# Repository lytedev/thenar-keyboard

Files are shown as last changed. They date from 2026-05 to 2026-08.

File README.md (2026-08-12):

# Thenar

A column-staggered, fully-wireless split keyboard with scrollwheels — 56 keys (28 per half + thumb cluster). Choc-spaced, hotswap, Nice!Nano + ZMK.

## Repositories

- **Primary**: <https://git.lyte.dev/lytedev/thenar-keyboard>
- **Mirror (GitHub)**: <https://github.com/lytedev/thenar-keyboard>
- **Sibling model**: [hypothenar](https://git.lyte.dev/lytedev/hypothenar-keyboard) — the pick-and-place (JLCPCB PCBA) sibling: same layout, completely different electronics ([GitHub mirror](https://github.com/lytedev/hypothenar-keyboard))

- Choc-spaced, hot-swappable
- Scrollwheel (`EVQWGD001`) on both sides
- Strong pinky stagger (0.66) and a 5 deg. pinky splay
- Fully wireless built for Nice!Nano + ZMK (no TRRS jack)
- Nice!View support (5 pin connector)
- Reversible PCB
- 3d printable magnetic case, switchplate and MCU cover

## Gallery

TODO: Take photos of the assembled Thenar and add them here.

## Firmware

Natively supports [ZMK](https://zmk.dev/). Build + flash via the flake:

```sh
nix build .#firmware             # both halves
nix run .#flash -- left          # build + flash (double-tap reset when prompted)
nix run .#flash -- right
```

The shield definition + keymap live in [`config/`](./config/).
See `config/README.md` for the full firmware development workflow,
including hash-pinning the Zephyr SDK on first build.

## Build guide

[see the docs](./docs/) — [build](./docs/build.md), [routing](./docs/routing.md). Both are LLM-drafted and unverified; treat them as starting points until someone has built and routed a Thenar end-to-end.

## Development

The build has two phases:

1. **Ergogen produces a scaffold** — KiCad PCBs with all the footprints
   placed and nets assigned, but **no copper routing**. This is the
   starting point.
2. **A human routes the scaffold in KiCad by hand** and commits the
   result to `thenar/routed/`. Gerbers are then exported from the
   committed routed file, not from the ergogen scaffold.

This is unavoidable: ergogen is a layout generator, not an autorouter, and
a useful keyboard PCB needs every net wired up by hand to fit two layers.

### Flake packages

```sh
nix build .#scaffold          # ergogen -> KiCad PCBs (UNROUTED, for hand-routing)
nix build .#gerbers           # gerbers from thenar/routed/keyboard.kicad_pcb
nix build .#gerbers-zip       # ^^ zipped, ready to upload to JLCPCB etc. (default)
nix build .#switchplate-step  # STEP model of the switchplate (1.2mm)
nix flake check               # verifies thenar/routed/ placement matches scaffold
```

Each `result` symlink points at the artifact in `/nix/store`. For an
interactive shell with `ergogen`, `kicad-cli`, and `zip` available:

```sh
nix develop
```

### The two paths to fab-ready gerbers

- **Use the committed routed PCB.** `nix build .#gerbers-zip` and upload
  the result. This is the default path and the only one that has a chance
  of working without you doing any routing yourself.
- **Route your own.** Run `nix build .#scaffold`, open
  `result/pcbs/keyboard.kicad_pcb` in KiCad, route every net, save the
  routed file over `thenar/routed/keyboard.kicad_pcb`, then
  `nix build .#gerbers-zip`. If you fork the repo, commit your routed
  PCB so anyone using your fork gets it for free.

`nix flake check` runs `check-routing-drift`, which compares footprint
placement between the freshly-generated scaffold and the committed
`thenar/routed/` PCB. If you edit `thenar/ergogen/config.yaml` without
re-merging into the routed file, this check will fail loudly.

## License

MIT — see [LICENSE](LICENSE).

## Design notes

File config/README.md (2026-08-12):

# Thenar ZMK config / shield

The Thenar ZMK shield module + a build setup so `nix build .#firmware`
and `nix run .#flash -- (left|right)` work locally without GitHub
Actions.

## Building + flashing

```sh
# Build both halves -> a derivation containing zmk_left.uf2 + zmk_right.uf2.
nix build .#firmware

# Or just one half (each produces a .uf2 directly):
nix build .#firmware-left
nix build .#firmware-right

# Flash one half. Double-tap reset on the Nice!Nano when prompted.
nix run .#flash -- left
nix run .#flash -- right
```

The first build will fail with a `zephyrDepsHash` mismatch — paste the
hash nix reports into `flake.nix` (`zephyrDepsHash = ...`) and rebuild.
This hash pins the Zephyr SDK + west modules so subsequent builds are
hermetic.

## Files

- `west.yml` — west manifest. Pulls upstream ZMK and points west at this
  directory's `boards/` for shield discovery.
- `build.yaml` — ZMK CI matrix (for GitHub Actions / similar). Not used
  by the local nix build, but useful if you want to add CI later.
- `thenar.keymap` — the keymap zmk-nix's `buildSplitKeyboard` picks up.
  The only keymap in the repo; edit here.
- `boards/shields/thenar/`
  - `Kconfig.shield` / `Kconfig.defconfig` — Kconfig entries for the shield.
  - `thenar.dtsi` — matrix transform, encoder, sensor declarations.
  - `thenar-layouts.dtsi` — physical key positions (for ZMK Studio).
  - `thenar_left.overlay` / `thenar_right.overlay` — per-half GPIO + SPI.

## Hardware specifics

- **Matrix**: 5×12 (5 scan rows × 12 columns; 6 per half with `col-offset=6` on right).
- **Diode direction**: `col2row`.
- **Encoder (EVQWGD001 scrollwheel)**: `alps,ec11` compatible. Left half
  uses Nice!Nano P20/P21, right uses P2/P3.
- **Display (Nice!View)**: SPI0; left CS=P4, right CS=P19.

## Forking for a personal keymap

Easiest path: clone this repo, edit `config/thenar.keymap`, build with
`nix build .#firmware-left` / `nix build .#firmware-right`. Your keymap
edits stay in your fork.

For the "proper" ZMK ecosystem flow (separate config repo that pulls in
the shield as a remote module), point your `config/west.yml` at this
repo's `config/boards/` directory and define `shield: thenar_left` /
`thenar_right` in your build matrix.

## TODO before the firmware is fully verified

- **Matrix transform verification**: the mod-row matrix coords (`RC(4,1..4)`
  and `RC(4,7..10)`) were derived from `thenar/ergogen/config.yaml`'s
  `column_net`/`row_net` overrides. Could be off by one in the mod row.
  Press every key after flashing and check ZMK's matrix scan output.
- **Physical layout refinement**: `thenar-layouts.dtsi` coords are
  placeholder approximations of the corax layout adjusted for our
  extra outer-num key. Real values come from a built keyboard.
- **`thenar.zmk.yml`**: ZMK Studio metadata, add once the layout's stable.

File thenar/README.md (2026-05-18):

# Thenar

A 56-key column-staggered split keyboard with scrollwheels. 28 keys per half (5×6 matrix minus skipped corners + 2 thumb keys + scrollwheel).

## Bill of materials

**Essentials**:
| **Item** | **Count** | **Note** |
|---|---|---|
| Keyboard PCB | 2 | |
| Nice!Nano | 2 | |
| 12 pin headers and sockets | 4 | You can use through-hole diode legs as pins. Sockets spacing: 2.54mm, Socket height: Using minimal height sockets might not leave enough room to mount the battery under the MCU. 3DS1002-01-1*20V13-JK by CONNFLY are a good choice, but you can also use lower ones and longer legs instead. Spiltkb has a good [guide on mounting](https://docs.splitkb.com/hc/en-us/articles/360011263059).  |
| LiPo battery (301230) | 2 | 110mAh |
| Kailh Choc v1 switches (PG1350) | 56 | |
| Keycaps | 56 | |
| Kailh Choc hotswap sockets | 56 | |
| Encoder EVQWGD001 | 2 | |
| Diodes 1N4148W | 58 | for each key + encoder |
| Buttons | 2 | reset buttons; 2 pins through-hole, tactile, 3x6x4.3mm |
| Slider Switches | 2 | on/off switches; SMD, C128955 |
| USB-C Cable | 1 | for copying the firmware 

**Optional (Displays, 3d printed case)**:

| **Item** | **Count** | **Note** |
|---|---|---|
| Nice!View + mounts | 2 | |
| Switchplate | 2 | Height: 1.2mm; either 3d printed or cut pcbs. [stl](./3dprints/switchplate/) |
| Case (Left + Right) | 1 | see [here](./3dprints/case/). |
| Silicone feet | 8 | |

## Firmware

A ZMK shield module ships in this repo at [`firmware/`](../firmware/).
See `firmware/README.md` for how to wire it into your personal
ZMK config. The module defines the matrix, encoder, and display
hardware; the default keymap is minimal QWERTY for first-flash
verification — you'll want to fork it into a separate config repo
and customise.

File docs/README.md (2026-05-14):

# Thenar docs

- [build.md](./build.md) — assembly walkthrough (order PCBs, solder, flash).
- [routing.md](./routing.md) — how to take the ergogen scaffold to a
  routed PCB ready for fab. Only needed if you are routing yourself; the
  committed `thenar/routed/` PCB is the default path.

Both guides are currently LLM-drafted and unverified. Corrections welcome
once anyone has actually built or routed a Thenar.

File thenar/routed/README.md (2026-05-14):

# Routed PCB

This directory holds the **manually-routed** KiCad PCBs that gerbers are built
from. Ergogen places footprints and assigns nets, but does not route copper —
that step has to be done by hand in KiCad. The result of that hand-routing
lives here and is committed.

## Workflow

1. `nix build .#pcbs` produces the ergogen scaffold (footprints + nets, no
   traces) at `result/pcbs/keyboard.kicad_pcb`.
2. The first time, that scaffold is copied verbatim into this directory as a
   seed. You then open it in KiCad and route the traces by hand. Commit the
   routed file.
3. `nix build .#gerbers` reads the routed file *from here* — not from the
   ergogen output — and produces fabricatable gerbers.
4. If you edit `thenar/ergogen/config.yaml` (e.g. moving a key, adding a
   footprint), the ergogen scaffold and this routed file go out of sync.
   Run `nix flake check` (or `nix build .#check-routing-drift`) to catch
   that — it compares footprint placement between the freshly-generated
   scaffold and this committed PCB. When drift is detected, you need to
   merge the new footprint placement back into the routed PCB in KiCad
   (KiCad can do this incrementally via "Update PCB from Schematic" style
   workflows, but with ergogen the simplest path is usually: open the new
   scaffold, copy your routing over from the old routed file, and re-save).

## Current state

> **⚠️ Currently unrouted.** The files here are a verbatim copy of the
> ergogen output. They will produce empty/unusable gerbers until someone
> opens them in KiCad and routes the traces. Do **not** order PCBs from
> the current gerber output.

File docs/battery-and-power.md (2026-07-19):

# Battery & power

How the thenar is powered, and the clean split between **rev1 (rc1)** —
the boards already fabricated, which need a battery-wiring rework — and
**rev2** — the updated design that fixes it properly.

> **Revisions.** `git tag hw-rev1` freezes the as-fabricated rev1 PCB.
> `main` evolves into rev2 in place; recover rev1 files with
> `git show hw-rev1:thenar/routed/keyboard.kicad_pcb`.

## Background: how the nice!nano v2 power path works

One fact drives everything below: on the nice!nano v2 the **battery, the
onboard charger's output, and the MCU's supply are all the same node —
`B+` / VDDH**.

- **B+ / B-** (underside pads): the battery connects here. B+ feeds both
  the onboard charge IC (charges from USB 5 V) *and* the nRF52840's
  **VDDH**, which is the pin ZMK measures for battery level.
- **RAW**: a *separate* 5 V input that feeds only the 3.3 V regulator.
  RAW is **not** charged and **not** sensed.

So a cell on RAW powers the board but is invisible to both the charger
and the gauge. And because B+ = charger = MCU supply are one node, you
**cannot** hard-switch the MCU off while still charging the cell — those
are the same wire. "Off but charging" is only achievable *electronically*
(ZMK soft-off, ~µA), not with a mechanical cut. Both facts shape the
rev1 rework and the rev2 design.

---

## rev1 (rc1): the as-fabricated boards

### The problem

`thenar/ergogen/config.yaml` (at `hw-rev1`) wires **battery+ → slider →
the nice!nano RAW pin**; the B+/B- pads are unconnected. Consequences on
a board in hand:

- **Battery level reads a flat ~0%** — VDDH/B+ sits at ~0 V, so ZMK
  computes 0% regardless of real charge. (Multimeter check: B+ to GND ≈
  0 V, RAW to GND ≈ cell voltage.)
- **USB does not charge the LiPo** — the charger charges B+, which has no
  cell. USB powers the board but the battery only drains. Charge the cell
  externally until reworked.

Not a firmware bug — ZMK reads the board's built-in VDDH sensor and can't
be pointed at RAW. It's a wiring problem, forced by the footprint:
`mcu_nice_nano.js` exposes only the castellated edge pins (RAW/GND/VCC/
RST/Pxx) and **no B+/B- pads**, so RAW was the only power-input pad
available.

### The rework (existing boards)

The nice!nano is socketed on headers with the LiPo sitting in the gap
underneath it, so the module's underside B+/B- pads face the battery —
a short direct wire.

**Basic (working battery, ~5 min):**

1. Solder LiPo **+ → module B+**, **- → module B-** (B- is just GND).
2. Take the cell **off** the JST/slider/RAW path (don't leave it on both
   B+ and RAW — that's a conflict).
3. Result: correct battery %, USB charging works. The **slider is now
   dead** (it sat in the RAW path); "off" is ZMK's automatic deep-sleep.

**Advanced (also get the slider back as a soft-off switch):** additionally
rewire the slider off the power rail and onto spare GPIO **P0** (other
terminal to GND), and enable soft-off in firmware (see rev2 firmware
notes — the same config works on a reworked rev1 board). Then the slider
becomes a real on/off that still charges while off.

---

## rev2: updated power design

Goal the user asked for: **the slider turns the keyboard off, and it can
still charge while off.** Given the nice!nano constraint above, that means
**soft-off**, not a hard cut.

### Design

- **Battery → B+/B-.** The board gains labeled B+/B- solder pads (with
  silk "→ nice!nano B+/B-") in the battery cavity; the builder runs the
  short wire up to the module. Nothing routes to RAW. This restores
  sensing + USB charging by construction.
- **Slider → spare GPIO `P0`** (not the power rail). Wired as a ZMK
  **soft-off trigger + wake source**: slide off → System OFF (~5–15 µA);
  slide on → wake.
- **Charging is autonomous** — the onboard charger runs regardless of MCU
  state, so USB charges the cell whether awake or in soft-off. ✅

### What users get (matches commercial/premium wireless UX)

Plug in USB → it charges. OS shows a real battery %. Flip the slider →
stops typing, sleeps at µA. Flip back → wakes instantly, BT bond intact.
Charges in any switch position — like a Logitech/Apple keyboard, unlike
the common DIY hard-cut switch.

### The one tradeoff

Soft-off is ~µA, not a *true* zero-current disconnect — B+ stays lightly
energized. So it's slightly weaker than a hard battery cut for the
**spill** scenario. On a nice!nano you can't have both hard-disconnect
*and* charge-while-off; rev2 chooses charge-while-off. See
[spill-protection](spill-protection.md) — its "cut battery power" step is
now a soft-off, not a hard cut.

### Firmware (soft-off)

rev2 (and advanced-reworked rev1) needs ZMK soft-off enabled and the P0
slider configured as a soft-off trigger + wake source. Battery reporting
stays enabled — it's correct the moment a board has the cell on B+/B-.

Kept **out of the active firmware** deliberately: it can't be validated
until a board actually has the slider on P0, and the exact soft-off DT is
ZMK-version-specific. Apply this once you've reworked/built a rev2 board,
then bench-test. Reference: <https://zmk.dev/docs/features/soft-off>.

`config/thenar.conf`:

```
CONFIG_ZMK_PM_SOFT_OFF=y
```

Shield overlay — scaffold (validate against ZMK v0.3.0's soft-off API and
**confirm the P0 → &pro_micro/&gpio index** against the nice!nano pinout
before flashing):

```dts
/ {
    soft_off_key: soft_off_key {
        compatible = "gpio-keys";
        key {
            // P0 slider -> GND (ACTIVE_LOW). Map <PIN> to the nice!nano
            // P0 pad's actual GPIO - do NOT assume; check the pinout.
            gpios = <&pro_micro PIN (GPIO_ACTIVE_LOW | GPIO_PULL_UP)>;
        };
    };
    soft_off_scan: soft_off_scan {
        compatible = "zmk,kscan-gpio-direct";
        input-keys = <&soft_off_key>;
        wakeup-source;
    };
    soft_off_wakers {
        compatible = "zmk,soft-off-wakeup-sources";
        wakeup-sources = <&soft_off_scan>;
    };
};
```

Then bind `&soft_off` to the soft-off scan's key (per the ZMK doc's
dedicated-kscan pattern). Slide off → `&soft_off` fires → System OFF;
slide on → the wakeup source re-enables the board.

**Spare GPIO confirmed:** `P0` (and `P1`) break out to self-named nets on
the nice!nano footprint, used nowhere else in the matrix/encoder/display,
so P0 is free for this.

### Implementation status

- [x] Documented (this file) + rev1 frozen at `hw-rev1`
- [x] `thenar/ergogen/config.yaml`: battery+ off RAW → isolated
      `BAT_BPLUS` wire-out pad; slider → `SOFT_OFF` (nice!nano P0) / GND;
      silk labels. Validated: `ergogen` regenerates cleanly, `switch_from`
      gone, `BAT_BPLUS`/`SOFT_OFF` nets present.
- [x] Firmware soft-off scaffold documented (above), kept out of active
      firmware until there's hardware to validate it on
- [ ] **Re-route `thenar/routed/keyboard.kicad_pcb`** — it is now
      rev1-stale vs the rev2 ergogen source. Regenerate with
      `nix build .#routed-auto` (~25 min, ~95%), finish the last traces +
      DRC in KiCad, then `cp` into `thenar/routed/`. The `routing-check`
      flake check will fail until this is done (placement drifted).
- [ ] Bench-test soft-off + charge-while-off on a reworked board

### Reroute recipe (two paths)

The rev2 electrical delta is tiny (a couple of traces in one corner), so
you don't need a full reroute — pick whichever is less work:

**Path A — delta-patch your hand-routed board (recommended).** Open the
current `thenar/routed/keyboard.kicad_pcb` (your good rev1 hand-route) in
KiCad and change only these four pad nets:

| Pad | net now | net for rev2 |
|-----|---|---|
| battery **+** | `switch_from` | `BAT_BPLUS` (isolated — no trace; it's the B+ wire-out) |
| slider pad 1  | `switch_from` | `SOFT_OFF` |
| slider pad 2  | `RAW` | `GND` |
| nice!nano **P0** | `P0` | `SOFT_OFF` |

Then: delete the `switch_from` traces (battery+↔slider) and the
slider→RAW trace; route one short trace slider pad1 → P0 (`SOFT_OFF`);
let slider pad2 tie to `GND` (via the ground zone, maybe a stub); add the
two silk labels; DRC. ~99% of the hand-routing is untouched.

*(Scriptable via `pcbnew` but not done here — the edit can't be visually
verified from a headless session and the delta is small enough that
doing it in-GUI, where you see + DRC it, is safer.)*

**Path B — full autoroute (fallback).** `nix build .#routed-auto`
(~25 min, ~95%) machine-routes the whole board from the rev2 scaffold;
finish the last ~5% + DRC in KiCad. Downside: throws away the rev1
hand-routing, so you re-verify everything. A fresh build already sits at
`/tmp/thenar-routed-rev2/keyboard.kicad_pcb` (gc-rooted) if useful as a
reference — note `BAT_BPLUS` is intentionally a single-pad net (no trace).

Either path lands in `thenar/routed/keyboard.kicad_pcb`; commit the
finished board and the `routing-check` goes green again.

---

## The hypothenar does NOT have the rev1 problem

The hypothenar is a from-scratch power design (MS88SF3 + its own TP4056 +
LDO + sense divider) that routes **everything to one `VBAT` net** — cell,
charger BAT pin, MCU VDDH, and a GPIO-switched ADC divider all share it —
so it senses and charges the real cell. See
`hypothenar-keyboard/docs/power-budget.md`. Because it has its *own*
charge IC (not the nice!nano's fused B+ node), a true **hard-off that
still charges** is designable there (battery always on the TP4056, a load
switch to the MCU) — a v-next consideration, not a v1 thing. Bring-up
check: confirm the divider's high side is on `VBAT` (post-slider).

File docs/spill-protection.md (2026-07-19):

# Spill protection

Making the thenar survive a desk spill. This is **splash + humidity
resistance** — "I knocked my coffee over, cut power fast, let it dry" —
not submersion. Three layers, cheapest first; the coating is the one
that takes real work.

## 1. Behaviour (free, most important)

Electronics rarely die *wet*. They die *wet and powered* — electrolytic
corrosion and shorts happen while current flows. So the moment liquid
hits:

1. **Slide the power switch OFF** (cuts the battery at the board edge —
   no case-opening needed; the case v2 has a slot for it).
2. **Unplug USB.**
3. **Let it dry for days** before repowering. Rice/desiccant helps;
   heat above ~50 °C does not (bad for the LiPo).

The slider being a fast, accessible battery cutoff is why it earns its
place. This step alone saves most spilled boards.

> **Caveat by revision** (see [battery-and-power.md](battery-and-power.md)):
> the slider is a true hard cutoff only on **rev1 as-fabricated** (battery
> → slider → RAW). After the rev1 battery rework (LiPo → B+/B-) the slider
> goes dead, and on **rev2** it becomes a soft-off GPIO (~µA, not a hard
> disconnect). So on a reworked/rev2 board, "cut power fast" means the
> soft-off switch, which is slightly weaker for spills — pull the USB and
> physically disconnect the LiPo if you want a true kill.

## 2. Case drain slots (free, in case v2)

`thenar/scripts/case.scad` puts drain slots in the floor so liquid that
gets through the switch-plate cutouts exits instead of pooling against
the PCB. Print the current case (`nix build .#case-stl`).

## 3. Conformal coating (the real protection, ~$15 + care)

A thin insulating film over the electronics that shrugs off splashes
and humidity.

### Use acrylic, not silicone

For a **hotswap, tinkerable** board the deciding factor is
*reworkability*, not raw waterproofing:

- **Acrylic** (MG Chemicals 419D brush-on, or 4223 aerosol) is
  solvent-removable and you can still solder through it — so a future
  switch/diode fix stays possible. Cheap, easy, forgiving.
- **Silicone** repels liquid droplets slightly better but is miserable
  to rework or solder near, and actually allows ~10× more moisture
  *vapour* penetration than acrylic. Wrong trade for a board you open.

Sources: [acrylic vs silicone guide](https://www.andwinpcb.com/acrylic-vs-silicone-vs-urethane-conformal-coating-complete-selection-guide-for-pcb-protection/),
[Techspray essential guide](https://www.techspray.com/the-essential-guide-to-conformal-coating),
[Titoma waterproofing methods](https://titoma.com/blog/conformal-coating/).

### The skill is MASKING (do not skip)

Coating is easy; masking is where boards get bricked. Mask (keep BARE)
everything electromechanical or that mates / gets soldered. Coating a
contact kills it. Pre-flight mask list for the thenar:

- [ ] All 28 **hotswap sockets** (the leaf contacts)
- [ ] The **nice!nano header pins AND the female sockets**
- [ ] **USB-C** connector contacts + shield
- [ ] **SWD pads** and the **reset** tactile switch
- [ ] **Slider switch** contacts
- [ ] **Encoder** push + rotation pads
- [ ] **Display header** (nice!view)
- [ ] **Battery** solder pads / JST
- [ ] Screw holes (for clean threads) — optional

Coat freely everywhere else: the diodes, all traces, the passives, the
exposed copper between components.

Masking materials: Kapton tape is ideal (leaves no residue), or liquid
latex mask painted on and peeled off after. A toothpick lifts tape
edges cleanly.

### The nice!nano

**Leave it socketed; coat it separately or not at all.** It's a
replaceable daughterboard — the socket exists so you can swap it. If
you coat it, do so off-board with its pins masked; or skip it (it has
an RF shield can already, and you want its USB/charge circuitry
accessible). The **main PCB** is what benefits most.

### Application

- Do it **only after the board is 100 % working and you have stopped
  reflowing joints** — this is a finishing step, not a bring-up one.
- Two **thin** coats beat one thick one. Brush on, let flash off
  (~15 min for acrylic), second coat, then full cure per the can
  (hours). Ventilate.
- Test fit a switch into a masked socket after curing to confirm no
  coating crept into a contact.

## What NOT to do

- **Potting / epoxy fill** — permanent, un-repairable, kills hotswap.
  Wrong for a keyboard.
- **Mail-in "nano-coating" services** — overkill; DIY acrylic matches
  them for this use.
- Treating any of this as **submersion-proof**. It is not.

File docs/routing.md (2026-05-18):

# PCB Routing Guide

> **⚠️ LLM-generated, unverified.** Written by Claude based on the flake
> layout and general KiCad practice, not from an actual routing pass on
> this board. Treat as a starting checklist; expect to adjust as you
> discover what the real PCB needs. Corrections welcome after a successful
> route.

This walks through getting from the ergogen scaffold to a hand-routed PCB
that gerbers can be exported from. The output of this process is a
committed `thenar/routed/keyboard.kicad_pcb` that everyone else can fab
without repeating the work.

## 1. Open the scaffold in KiCad

From the repo root:

```sh
nix develop -c kicad thenar/routed/keyboard.kicad_pro
```

That opens the committed (currently unrouted) PCB inside the flake's
KiCad. The `.kicad_pro` project file is generated by the scaffold step
and ships pre-configured net classes and design rules (see
[Section 4](#4-design-rules-pre-configured)).

If you want to start from a pristine scaffold instead — for
example, after editing `thenar/ergogen/config.yaml` — regenerate first:

```sh
nix build .#scaffold
cp result/pcbs/*.kicad_pcb result/pcbs/*.kicad_pro thenar/routed/
chmod u+w thenar/routed/*
nix develop -c kicad thenar/routed/keyboard.kicad_pro
```

(`result/` is a symlink into `/nix/store`, which is read-only — that's
why the copy + `chmod` is needed.)

## 2. Get oriented

Ergogen has already done the boring parts:

- All footprints are placed: switches, hotswap sockets, diodes, MCU,
  display, scrollwheel, slider, reset button, screw holes.
- Every net is named (e.g. `row0`, `col4`, `GND`, `VCC`, `BAT+`).
- The board outline is on Edge.Cuts.

What is missing:

- **Copper traces.** Every net needs its connections drawn.
- **Power planes / fills.** Typically a GND pour on both layers.
- **Vias** wherever a trace needs to switch layers.

Pull up the **net inspector** (View → Net Inspector, or `Inspect → Net
Inspector` depending on KiCad version) and you should see all nets
listed with current length 0 and pad count > 1 — i.e. unrouted.

## 3. Run DRC once before you start

`Inspect → Design Rules Checker`. Expect a wall of "unconnected pads"
errors — that's fine, that's what you're about to fix. Note any errors
that are *not* unconnected-pads warnings (e.g. footprint overlap, courtyard
violations), because those are real and routing won't fix them.

## 4. Design rules (pre-configured)

The scaffold's generated `.kicad_pro` already ships with sensible defaults
for a choc-spaced, two-layer, hand-routed split keyboard:

| Setting | Value |
|---|---|
| Minimum trace width | 0.20 mm |
| Default trace width | 0.25 mm |
| Power trace width | 0.40 mm |
| Minimum via diameter  | 0.60 mm |
| Minimum via drill | 0.30 mm |
| Minimum clearance | 0.20 mm |

Power-class nets (`VCC`, `GND`, `BAT+`, `RAW`, `VBUS`) automatically get
the wider trace width. JLCPCB's standard 2-layer process is comfortable
with all of these.

If you want to change them, see `thenar/scripts/write_kicad_pro.py` —
the rules and net classes are defined there as constants and regenerated
every time `.#scaffold` runs. `File → Board Setup` in KiCad will also
let you tweak them interactively, but those edits will be lost the next
time the scaffold is regenerated.

## 5. Route

Pick an order that minimises rework. A pattern that tends to work for
split keebs:

1. **Power first.** Route `VCC` and `BAT+` from the slider switch /
   battery pads to the Nice!Nano. Wide trace (0.4 mm+).
2. **Matrix rows next.** Each `colN` net runs down a column from key to
   key — easy, nearly straight runs.
3. **Matrix columns.** Each `rowN` net runs across all keys in a row.
   These are trickier because they cross the column traces; use the
   opposite layer or hop over with a via.
4. **MCU + display + scrollwheel signals last.** They are the most
   constrained but also the fewest nets.

**You do not need to route GND.** The scaffold ships with two filled
zones (one on F.Cu, one on B.Cu) tied to the GND net that cover the
whole board outline. Every GND pad on the board ties into the pour
automatically. If you want to see the fill while routing, hit `B` in
pcbnew to refill zones; `Ctrl+B` un-fills them so you can see traces
beneath. Gerber export refills them too via `--check-zones`, so the
filled-or-not state of the saved file doesn't affect what gets fabbed.

KiCad's interactive router (default `X` shortcut) handles most of this.
"Walk around" mode is usually the right choice for hand routing; "Shove"
is helpful in tight clusters near the MCU.

## 6. Verify

```sh
# inside kicad
Inspect -> Design Rules Checker     # must come up clean (zero unrouted nets)
```

Then save, exit KiCad, and from the shell:

```sh
nix flake check                # confirms footprint placement matches the scaffold
nix build .#gerbers            # exports gerbers from the routed file
nix build .#gerbers-zip        # zipped, ready to upload
```

If `nix flake check` fails with a "routing drift" error, you've edited
the ergogen config since you started routing — re-merge by hand and
re-check.

## 7. Commit

```sh
jj diff -- thenar/routed/      # sanity check
jj describe -m "pcb: route keyboard matrix + MCU + scrollwheel"
jj bookmark set main -r @
jj git push
```

Once pushed, anyone else building the keyboard can skip this whole
document and just run `nix build .#gerbers-zip`.

## Tips

- **Use `F.Cu` for horizontal runs, `B.Cu` for vertical** (or vice versa)
  as a default convention. It dramatically reduces the number of vias.
- **Don't route under switch bodies if you can avoid it.** A scratched
  trace from a wonky switch is a miserable thing to debug.
- **The reversible PCB constraint** means every footprint exists in
  mirrored form on both layers. Pay attention to which side each pad is
  on; routing to the wrong side connects to the wrong half-keyboard.
- **Save often.** KiCad's autosave is fine but routing a full split
  takes hours and a power loss mid-session hurts.
- **Run DRC frequently**, not just at the end. Catching a clearance
  violation after one trace is fast; catching it after 200 is painful.

## Autorouting (freerouting)

The flake exposes a `.#routed-auto` package that runs the scaffold
through freerouting and produces a kicad_pcb with traces:

```sh
nix build .#routed-auto
# inspect:
nix develop -c pcbnew result/keyboard.kicad_pcb
# accept (replaces the committed hand-routed PCB):
cp result/keyboard.kicad_pcb thenar/routed/keyboard.kicad_pcb
chmod u+w thenar/routed/keyboard.kicad_pcb
```

`.#gerbers` always reads `thenar/routed/`, never the autoroute output
directly — so you can experiment with `.#routed-auto` without
clobbering a careful hand-routed PCB until you explicitly copy over.

### What to expect

On this design, freerouting gets to **~91% routed** and plateaus there.
A typical run leaves **~23 unrouted nets** in:

- **`col4`** — the mod-row net, which spans nearly the full width of the
  board (thumb cluster → mod-row switches → scrollwheel → Nice!Nano).
- **Other matrix rows/cols** (`row1`, `row2`, `outer_*`, `layer_cluster`,
  `index_mod`, etc.) where freerouting can't find a 2-layer path under
  the GND zone and around the Nice!Nano.
- **`sw_a`/`sw_b`/`sw_c`/`sw_d`** — short 2 mm hops between the encoder
  pads and their adjacent jumper pads, blocked by freerouting's
  conservative pad-clearance handling.

Freerouting also uses dramatically fewer vias than a human router. On
one comparison run: human used **102 vias**, autoroute used **43**. The
autoroute "goes around" obstacles where a human would "drop a via, run
under, come back up." This is the root reason it can't close the last
9% — the score function penalises vias more than it values connectivity.

### Tuning

`thenar/scripts/freerouting.json` is freerouting's config. Notable knobs:

- `router.scoring.via_costs` — lower = more vias allowed. We set this to
  10 (default 50); does help marginally but doesn't change the fundamental
  bias.
- `usage_and_diagnostic_data.disable_analytics: true` — prevents
  freerouting from retrying its 501-returning telemetry endpoint for an
  hour after each run. Keep this on.

Implementation gotchas in `thenar/scripts/autoroute.py`:

- KiCad's Specctra DSN exporter chokes on `text.js` (zero pads) and
  `battery.js` (reused module name). The script strips both before DSN
  export and re-applies routing to the original board via SES import.
- The `(plane GND ...)` block KiCad emits for our GND zone makes
  freerouting treat the entire board as solid copper. We strip those
  plane declarations from the DSN.
- nixpkgs ships freerouting 2.2.1, which has a multithreaded race that
  crashes pass #1. The flake bypasses that by fetching v2.2.4 directly
  and wrapping it with `temurin-jre-bin-25`. Drop when nixpkgs catches
  up.
- Single-threaded (`-mt 1`) is used because v2.2.4 multithreaded mode
  doesn't fire its "stop on score plateau" heuristic and runs forever.

### Hybrid workflow (the realistic path)

The intended workflow given the above:

```sh
# 1. Generate an autoroute starting point (~5 min).
nix build .#routed-auto
cp result/keyboard.kicad_pcb /tmp/finish-routing/
chmod u+w /tmp/finish-routing/keyboard.kicad_pcb

# 2. Open in pcbnew and finish the ~25 remaining nets by hand.
#    Highlight unrouted via Inspect -> Design Rules Checker -> Unconnected
#    Items tab. Each entry has a "Go to location" button.
nix develop -c pcbnew /tmp/finish-routing/keyboard.kicad_pcb

# 3. When DRC reports 0 unconnected, copy over the committed PCB.
cp /tmp/finish-routing/keyboard.kicad_pcb thenar/routed/keyboard.kicad_pcb
```

### Comparing routings

`thenar/scripts/compare_routing.py` reports per-net length and via diff
between two routed PCBs. Useful for A/B-ing autoroute settings or
comparing your routing against an autoroute baseline:

```sh
nix develop -c kicad-python thenar/scripts/compare_routing.py \
    thenar/routed/keyboard.kicad_pcb /tmp/finish-routing/keyboard.kicad_pcb
```

Output columns are per-net: pad count, golden vs candidate trace mm,
via counts on each side. Sorted by candidate-minus-golden so the worst
deltas float to the top.

## Further reading

The upstream corax README cited FlatFootFox's ergogen-to-KiCad tutorial
as the reference it leaned on:
<https://flatfootfox.com/ergogen-introduction/>

Other useful references (search rather than dead-link):

- KiCad's official tutorials at <https://www.kicad.org/help/tutorials/>
- "ZMK split keyboard PCB" walkthroughs on YouTube — several creators
  cover the choc + Nice!Nano + Nice!View pattern end-to-end
- Looking at the routed PCBs in similar projects: the upstream
  [corax-keyboard](https://github.com/dnlbauer/corax-keyboard) repo's
  committed `corax54/pcbs/pcbs/keyboard.kicad_pcb` is essentially the
  same board minus one key; opening it side-by-side with the thenar
  scaffold is the fastest way to see how this one wants to be routed.

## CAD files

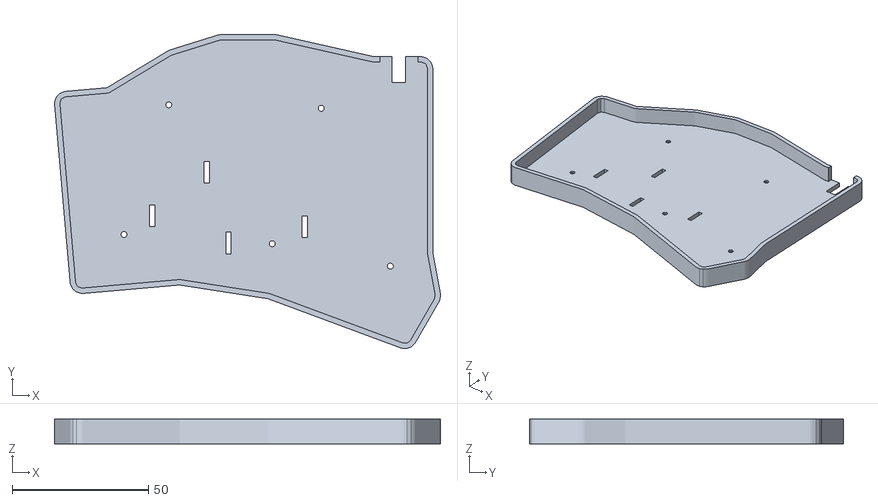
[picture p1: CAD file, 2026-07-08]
stl/thenar-case.stl
141.8 x 115.3 x 9.00

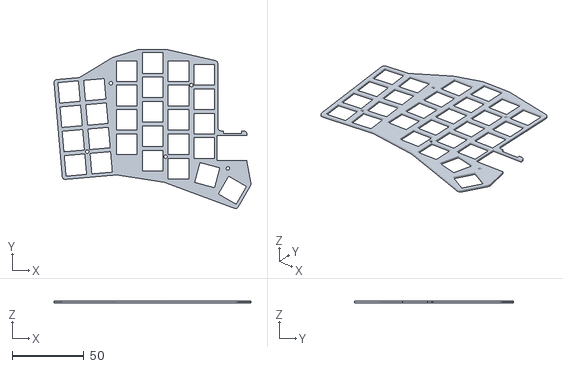
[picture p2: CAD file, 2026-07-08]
stl/thenar-switchplate.stl
137.0 x 110.5 x 1.30

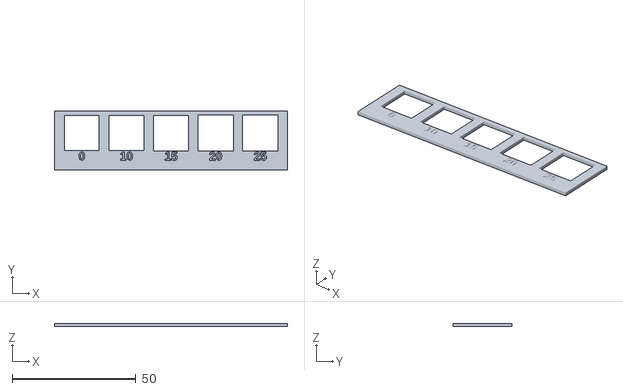
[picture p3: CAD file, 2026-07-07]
stl/thenar-switchplate-cal.stl
94.0 x 24.0 x 1.30

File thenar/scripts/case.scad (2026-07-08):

// 3D-printable bottom case tray for the thenar rc1.
//
// A simple tray the PCB sits in, component-side-down: a flat floor plus a
// perimeter wall grown as an outward offset of the ergogen `board` outline,
// so the cavity interior matches the PCB outline plus a small fit
// clearance. Wall height clears the Kailh Choc hotswap sockets (~3mm)
// under the PCB (1.6mm) with margin. The switchplate mounting screws pass
// through the floor at the same `screw`-tagged ergogen points the plate
// uses, with a shallow countersink on the underside for M2 flat heads.
// A full-height open-top notch in the wall clears the nice!nano's USB-C
// connector; its centre comes from the `mcu`-tagged ergogen point and it
// opens in +y (the nice!nano sits long-axis vertical with USB at the
// board's top edge).
//
// The outline is a single half; print one as-is and one mirrored in the
// slicer for the other half.
//
// v2 additions:
//   - Power slider access: the E73:SPDT_C128955 is an SMD slide switch
//     mounted component-side-down, so its actuator faces the case floor.
//     A floor slot under it, elongated along the actuator's travel axis,
//     lets you slide it with a fingernail/tool through the closed case.
//     Its position is derived from the same `mcu` ergogen point the USB
//     notch uses (slider = mcu point + slider_offset), so it can't drift.
//   - Drain slots: a few floor slots in the key area (away from the
//     battery/electronics zone at the top) so a desk spill that gets
//     through the switch plate exits instead of pooling on the PCB.
//
// NOT case concerns (corrected 2026-07): the reset button and the
// nice!nano charge LED are both on the TOP face; the case is a bottom
// tray, so it neither blocks nor needs to expose them.
//
// TODO(v2): battery pocket recessed into the floor.
// TODO(v2): standoffs/bosses under the screw points instead of relying on
//           the sockets resting on the floor.
// TODO(v2): VERIFY the encoder wheel-to-floor clearance on a printed
//           case. The EVQWGD001 mounts component-side-down; whether its
//           roller touches the floor depends on which component the PCB
//           rests on (sockets vs the encoder body) - not determinable
//           from the 2D footprint. wall_height gives ~5.4mm under-PCB
//           space; the encoder's under-board depth is ~4-5mm per the
//           datasheet, so it likely clears, but measure to be sure.
//
// All parameters are overridable via `openscad -D`:
//   dxf              path to the ergogen board outline DXF (the case
//                    perimeter; `case.dxf` is this same outline with the
//                    screw holes pre-subtracted, which offset() would
//                    distort, so the plain board outline is used and the
//                    holes are cut as cylinders below).
//   floor_thickness  floor plate height in mm.
//   wall_height      wall height above the floor in mm. Must clear
//                    hotswap sockets (~3mm) + PCB (1.6mm) + margin.
//   wall_thickness   perimeter wall thickness in mm.
//   clearance        gap between PCB outline and cavity interior in mm.
//   screw_hole       screw hole diameter in mm. Mirrors
//                    switchplate_screw_hole in ergogen/config.yaml.
//   screw_positions  [[x, y], ...] hole centres in DXF coordinates, as
//                    emitted by scripts/switchplate_holes.py.
//   csink_diameter / csink_depth
//                    underside countersink for the screw heads. Set
//                    csink_depth = 0 to disable.
//   usb_positions    [[x, y]] mcu point centre in DXF coordinates, as
//                    emitted by `scripts/switchplate_holes.py ... mcu`.
//   usb_dir          direction the USB connector faces, degrees in the
//                    DXF plane (90 = +y).
//   usb_notch_width  width of the USB wall notch in mm.
dxf = "board.dxf";
floor_thickness = 2.0;
wall_height = 7.0;
wall_thickness = 2.0;
clearance = 0.25;
screw_hole = 2.2;
screw_positions = [];
csink_diameter = 4.6;
csink_depth = 1.2;
usb_positions = [];
usb_dir = 90;
usb_notch_width = 14;
// How far the notch cutter reaches inward/outward from the mcu centre.
// Generous on purpose: inside the cavity it only cuts air.
usb_notch_reach = 30;

// Power slider floor slot. Position derived from the mcu point (which is
// passed in as usb_positions[0]): the slider zone is anchored to `mcu`
// with adjust.shift [-17.1, 0] in ergogen space, which lands +17.1mm in
// DXF y from the mcu centre. Slot elongated along the actuator's travel
// (the footprint is rotate:90, so travel runs along y = the board edge).
slider_offset = [0, 17.1];   // DXF offset from the mcu point to the slider
slider_slot_w = 5;           // across the actuator (x)
slider_slot_l = 11;          // along the travel axis (y): knob + full throw + finger
slider_slot_dir = 90;        // travel-axis direction, degrees (90 = +y)

// Drain slots in the floor (DXF coords), away from the top electronics
// zone. Board bbox is x 46..183, y -158..-48; these sit in the key area.
drain_positions = [[80, -112], [108, -122], [136, -116], [100, -96]];
drain_slot_w = 2;
drain_slot_l = 8;

eps = 0.01;
total_height = floor_thickness + wall_height;

difference() {
  union() {
    // Floor: full outline grown to the wall's outer face.
    linear_extrude(height = floor_thickness)
      offset(r = wall_thickness + clearance) import(dxf);
    // Wall ring: outer face minus cavity (outline + fit clearance).
    // offset(r=...) rather than offset(delta=...) so concave corners
    // of the outline don't self-intersect.
    linear_extrude(height = total_height) difference() {
      offset(r = wall_thickness + clearance) import(dxf);
      offset(r = clearance) import(dxf);
    }
  }

  // Switchplate mounting screws pass through the floor.
  for (p = screw_positions) {
    translate([p[0], p[1], -1])
      cylinder(h = total_height + 2, d = screw_hole, $fn = 32);
    if (csink_depth > 0)
      translate([p[0], p[1], -eps])
        cylinder(h = csink_depth, d1 = csink_diameter, d2 = screw_hole,
                 $fn = 32);
  }

  // USB-C notch: full wall height, open-top, floor left intact.
  for (p = usb_positions)
    translate([p[0], p[1], 0]) rotate([0, 0, usb_dir - 90])
      translate([-usb_notch_width / 2, 0, floor_thickness])
        cube([usb_notch_width, usb_notch_reach, wall_height + 1]);

  // Power slider access: a slot straight through the floor under the
  // slider's actuator, elongated along its travel axis.
  for (p = usb_positions)
    translate([p[0] + slider_offset[0], p[1] + slider_offset[1], -eps])
      rotate([0, 0, slider_slot_dir - 90])
        translate([-slider_slot_w / 2, -slider_slot_l / 2, 0])
          cube([slider_slot_w, slider_slot_l, floor_thickness + 2 * eps]);

  // Drain slots: small through-floor slots so a spill exits the tray.
  for (p = drain_positions)
    translate([p[0] - drain_slot_w / 2, p[1] - drain_slot_l / 2, -eps])
      cube([drain_slot_w, drain_slot_l, floor_thickness + 2 * eps]);
}

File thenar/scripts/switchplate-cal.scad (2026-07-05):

// Calibration coupon for the 3D-printed switch plate.
//
// Five 14mm Choc cutouts at increasing FDM shrink compensation,
// labeled with the compensation in hundredths of a mm (0, 10, 15, 20,
// 25). Print flat at the same settings you'll use for the real plate
// (0.15mm layers, 100% infill recommended), then press a Choc switch
// into each hole:
//
//   - too tight / needs force: move up
//   - clips engage with a firm push, no wobble: that's your value
//   - drops in loosely / wobbles: move down
//
// Then EITHER set that value as your slicer's hole-horizontal-
// expansion / XY-hole-compensation (and print the plate unmodified),
// OR rebuild the plate STL with -D print_compensation=<value>.
//
// Coupon is ~90x24mm, prints in ~10 minutes.
cutout = 14.0;          // matches switchplate_switch_cutout in ergogen
thickness = 1.3;        // match the plate
compensations = [0, 0.10, 0.15, 0.20, 0.25];
pitch = 18;             // spacing between cutout centres
margin = 2;

coupon_w = pitch * len(compensations) + margin * 2;
coupon_h = cutout + margin * 2 + 6;  // extra 6mm strip for labels

difference() {
  linear_extrude(height = thickness)
    square([coupon_w, coupon_h]);
  for (i = [0 : len(compensations) - 1]) {
    c = compensations[i];
    // Cutout, grown by the compensation on each side
    translate([margin + pitch * i + pitch / 2, margin + cutout / 2 + 6, -1])
      linear_extrude(height = thickness + 2)
        square(cutout + 2 * c, center = true);
    // Engraved label: compensation in hundredths (e.g. "15" = 0.15mm)
    translate([margin + pitch * i + pitch / 2, margin + 2, thickness - 0.4])
      linear_extrude(height = 1)
        text(str(c * 100), size = 3.5, halign = "center",
             font = "Liberation Sans:style=Bold");
  }
}

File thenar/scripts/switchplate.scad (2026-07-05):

// 3D-printable switch mid-plate for the thenar rc1.
//
// Extrudes the ergogen `switchplate` outline (which already carries the
// 14mm Choc switch cutouts and the scrollwheel cutout) and subtracts the
// mounting screw holes, which the PCB variant of the plate gets as KiCad
// footprints rather than as part of the DXF outline.
//
// The outline is a single half; print one as-is and one mirrored in the
// slicer for the other half.
//
// FDM printers produce interior cutouts 0.1-0.3mm undersized, so a
// plate printed at CAD dimensions grips switches too tightly. Two ways
// to compensate - pick ONE:
//   1. (preferred, no rebuild) slicer-side: Cura "Hole Horizontal
//      Expansion" or PrusaSlicer/Orca "XY hole compensation",
//      typically 0.15-0.25mm. Print scripts/switchplate-cal.scad
//      first to find your printer's value.
//   2. model-side: -D print_compensation=0.15 - grows every interior
//      cutout by that amount per side via offset(delta=-c). Side
//      effect: the outer perimeter shrinks by the same amount, which
//      is negligible at these values.
//
// All parameters are overridable via `openscad -D`:
//   thickness           plate height in mm. Kailh Choc clips want 1.2-1.4.
//   dxf                 path to the ergogen switchplate outline DXF.
//   screw_hole          mounting hole diameter in mm. Mirrors
//                       switchplate_screw_hole in ergogen/config.yaml.
//   screw_positions     [[x, y], ...] hole centres in DXF coordinates, as
//                       emitted by scripts/switchplate_holes.py.
//   print_compensation  mm of FDM shrink compensation per cutout side.
//                       Default 0 = CAD-true; use the slicer knob instead
//                       when possible.
thickness = 1.3;
dxf = "switchplate.dxf";
screw_hole = 2.2;
screw_positions = [];
print_compensation = 0;

difference() {
  linear_extrude(height = thickness)
    // offset(delta=-c) grows interior holes and shrinks the outer
    // boundary by c; at 0 it's a no-op.
    offset(delta = -print_compensation) import(dxf);
  for (p = screw_positions)
    translate([p[0], p[1], -1])
      cylinder(h = thickness + 2, d = screw_hole + 2 * print_compensation, $fn = 32);
}

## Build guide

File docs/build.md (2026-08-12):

# Build Guide

> **⚠️ This guide is LLM-generated and has not been verified by an actual
> build.** It was produced by Claude by adapting the upstream
> [corax build guide](https://github.com/dnlbauer/corax-keyboard/blob/main/docs/BuildGuide.md) —
> rewording the prose, updating counts (54 → 56 keys, 28 hotswaps + 29
> diodes per side), and replacing the upstream's image-per-step photos
> with text descriptions. The procedural content is paraphrased from the
> upstream guide rather than independently verified. Treat it as a
> starting point; expect to cross-reference the upstream guide and other
> ZMK split builds, and submit corrections after your first build.
>
> TODO: Replace prose with photos at each step. Sections for the Nice!View
> display and the 3D-printed case are still unwritten — the upstream guide
> left them as TODOs too.

Thenar's assembly is mechanically identical to the corax — same reversible
PCB, same MCU/scrollwheel/display layout — it just has one extra switch
position per half on the outermost column.

---

## Disclaimer

This guide is written from the perspective of someone who has already built
some keyboards. It is probably not very beginner-friendly. There are many
tricks and techniques for soldering and assembling keyboards that are not
covered in detail. If this is your first build, I strongly recommend reading
one or two more comprehensive guides on other keyboards first. A great one
to start with is the Sofle guide:
<https://josefadamcik.github.io/SofleKeyboard/build_guide_choc.html>

## PCB routing (one-time, before you can order)

> **⚠️ The committed PCB in `thenar/routed/` is currently a verbatim copy
> of the ergogen scaffold — it has all the footprints placed but no copper
> routing.** Building gerbers from it today produces an unfabricatable
> board. Someone has to route the traces by hand in KiCad before any
> useful gerbers can be produced. See `thenar/routed/README.md` for
> current status.

If you are the one doing the routing, see the dedicated
[routing guide](./routing.md) for the step-by-step. The short
version:

```sh
nix build .#scaffold
# Open result/pcbs/keyboard.kicad_pcb in KiCad and route every net.
# Save your routed version over thenar/routed/keyboard.kicad_pcb.
# (Repeat for switchplate if any changes are needed.)
nix flake check        # confirms footprint placement still matches the scaffold
```

If someone else has already routed and committed (the normal case once
this stabilises): skip this section, go straight to ordering.

## Ordering PCBs

Build the gerber zip from the flake:

```sh
nix build .#gerbers-zip
```

`result/thenar-gerbers.zip` is the file you upload to your PCB fab. I
recommend [JLCPCB](https://jlcpcb.com/) with these settings:

| | |
|---|---|
| Layers | 2 |
| PCB Thickness | 1.6 mm |
| Surface Finish | LeadFree HASL |
| Via Covering | Tented |
| Board Outline Tolerance | +/- 0.2 mm (Regular)|

## Building the keyboard

You need two PCBs — one for each hand. The PCB is reversible: the same
board is used for both halves, and which face of the board ends up facing
up (toward your fingers) determines whether it's the left or right half.

Two pieces of jargon to keep straight:

- The **up side** is the face that ends up pointing upward in the
  finished keyboard — the side your fingers see (through the switchplate
  and keycaps). Switches, MCU, battery, scrollwheel, reset, and screen
  all live on this face.
- The **down side** is the face that ends up pointing at your desk.
  Hotswap sockets, diodes, on/off switch, and jumpers live here.

To tell which face should be up for which hand, look at the silkscreen:

- On the left half, the up side has **"Left Hand Up"** silkscreened on it.
- On the right half, the up side has **"Right Hand Up"** silkscreened on it.

The opposite face of each is the down side. Before you start, mark the
intended up face of each PCB with tape or a post-it. Check before every
step that you are working on the correct side.

### Jumpers

There are **31 jumpers to bridge per half**, in three groups (counts
verified against the ergogen output):

- **MCU (Nice!Nano): 24** — two chevron jumpers per pin row (one on the
  left of the module, one on the right), 12 rows.
- **Display (Nice!View): 4** — one per display pin except the center
  VCC pin, which is the same net on both sides and has no jumper.
- **Scrollwheel (encoder): 3** — ENCA, ENCB, GND, next to the encoder
  footprint.

They make the MCU/display/encoder footprints reusable between the two
halves by letting you pick which side connects each net.

**Solder the jumpers ONLY on the down side of the PCB.** That is: when
building the left half (up side labelled "Left Hand Up"), solder the
jumpers on the "Right Hand Up" side. This is critical — soldering on
the wrong side will not work, and on the MCU jumpers in particular it
can short pins together and destroy the Nice!Nano on power-up.

The encoder group has jumper pads on both faces (three per face); the
same rule applies — bridge only the three on the down side and leave
the up-side group open. The up-side group is the other half's wiring.

Bridge each jumper with a small blob of solder across the two pads.

### MCU sockets

Solder the 12-pin sockets for the Nice!Nano. The sockets go on the up
side. A useful trick is to tape the sockets in position from the up
side, flip the board, and solder them from the down side while the tape
holds them flush.

If you want the LiPo battery to fit between the PCB and the MCU later,
use low-profile sockets (e.g. 3DS1002-01-1\*20V13-JK by CONNFLY) — and
see Splitkb's mounting guide for a thorough walkthrough of how to height
the MCU sockets correctly:
<https://docs.splitkb.com/hc/en-us/articles/360011263059>

### On/Off switch and reset button

The on/off slider switch (C128955) goes on the **down side** of the
board. This leaves clearance on the up side for the battery to sit
between the PCB and the MCU. The switch has 7 legs but only the 3
marked legs are electrically required — soldering the other tabs as
mechanical support is optional.

The 2-pin reset button goes on the **up side**: insert it from the up
side and solder the legs on the down side. Orientation does not matter.

### Scrollwheel

Before soldering the EVQWGD001 encoder, you need to trim some of its
legs and tabs so it fits the PCB cleanly:

- Cut off the foot on the left side of the encoder (looking at the
  encoder from the wheel side) — there is no matching hole for it on
  the PCB.
- Trim the overhang tabs along the long right edge of the encoder. The
  signal pins alone are sturdy enough to hold it in place, and trimming
  these makes the encoder much easier to seat without flexing or
  snapping a pin.

Place the encoder on the board (up side) and solder its pins from
the down side.

### Hotswap sockets and diodes

There are **28 Kailh Choc v1 hotswap sockets** and **29 diodes** (1N4148W
SMD) per side — one diode per switch plus one for the scrollwheel. Both
the sockets and the diodes are mounted on the **down side** of the board.

Diode orientation matters. Each 1N4148W has a marking (an arrow or a
white line) on one end indicating the cathode. Align that mark with the
arrow on the silkscreen for each diode footprint. If you are unsure how
to read diode polarity, look it up before placing any — flipped diodes
will silently break the matrix for the affected key.

Workflow that tends to work well: tin one pad of each footprint first
(diodes and hotswaps both), then place the part with tweezers and
reflow that pad to anchor it, then solder the remaining pad(s). For
the hotswaps, press the socket flat against the PCB while reflowing
the anchor pad — gaps cause inconsistent key heights and bad switch
seating.

### Battery

Solder the LiPo battery (301230, 110 mAh) to the up-side battery pads
below the MCU footprint. The pads are labelled `+` and `-` on the
silkscreen; black wire goes to `-`, red wire goes to `+`. Double-check
polarity with a multimeter before powering on — a reversed LiPo will
damage the Nice!Nano (and possibly catch fire).

The battery is intended to sit on the up side, tucked under the MCU.
You can mount it on the down side instead if you prefer; the pads work
either way as long as polarity matches the silkscreen.

### MCU

Add the Nice!Nano and solder the pins on the MCU side. The MCU sits on
the **up side, facing down** (components toward the PCB). If you
chose low-profile sockets, there should be enough room for the battery
to live underneath. If not, position the pins so the gap is large
enough — solder the first and last pin to set the height, check
clearance, then solder the rest.

### Switches and keycaps

Snap the Kailh Choc v1 switches (PG1350) into the hotswap sockets from
the up side. If you are using a switchplate, install it before the
switches — the switches clip into the plate first, then the whole
assembly presses down into the sockets.

Add keycaps.

## Display (Nice!View)

The firmware includes the nice!view shields, so a display works
plug-and-play once the hardware is in:

1. Bridge the **4 display jumpers on the down side** — the chevrons for
   MOSI, SCK, GND, and CS next to the display header position. The
   center pin (VCC) has no jumper; it's the same net on both faces.
2. Solder the 5-pin socket on the up side, next to the MCU.
3. Seat the nice!view. No firmware change needed — the same image runs
   with or without the display attached (the SPI writes are
   fire-and-forget).

## Flashing

`nix run .#flash -- left|right` builds and waits for the `NICENANO`
mass-storage device (double-tap reset to enter the bootloader), mounts
it with `udisksctl`, then copies the UF2. This needs a machine where
polkit will allow that mount — in practice, a local desktop session.

If it sits at "waiting for NICENANO" while `journalctl -k` shows the
bootloader enumerating (`Adafruit nRF UF2`, a new `/dev/sdX`), the
mount is what failed, not the double-tap. Fall back to serial DFU
below.

**Over SSH** (no desktop session, polkit refuses `udisksctl`): use the
bootloader's serial DFU channel instead — it only needs `dialout`
group. Convert the UF2 to hex + DFU zip and flash via `/dev/ttyACM0`:

```bash
# uf2 -> Intel HEX (UF2 blocks are self-addressed; app range starts at
# 0x26000). Converter lives in the repo: thenar/scripts/uf2_to_hex.py
python3 thenar/scripts/uf2_to_hex.py zmk_left.uf2 zmk_left.hex
adafruit-nrfutil dfu genpkg --dev-type 0x0052 --application zmk_left.hex dfu.zip
adafruit-nrfutil dfu serial --package dfu.zip -p /dev/ttyACM0 -b 115200
```

### Firmware troubleshooting notes (hard-won)

- **`config/thenar.keymap` is the keymap.** Per ZMK's config-folder
  convention, `config/<name>.keymap` and `config/<name>.conf` take
  precedence over any copies under `config/boards/shields/thenar/`.
  The shield used to carry a stub fallback keymap that silently rotted
  out of sync with the matrix transform; it is gone, and the top-level
  file is now the only one. The build log line `Using keymap file: ...`
  confirms which file won.
- **ZMK is pinned to a release tag in `config/west.yml` — keep it
  that way.** A `main` snapshot once built a 50 KB image with no USB
  interfaces and no BLE: the board enumerated but no key could ever
  register. If firmware behaves impossibly, check the pin and the
  linker's `FLASH:` usage line in the build log (healthy builds are
  several hundred KB).
- **New files are invisible to `nix build` until tracked.** The flake
  source only includes git-tracked files; in this jj repo, run `jj st`
  (any jj command snapshots) after creating a file, or the build
  silently uses the old tree.
- **Encoder rotation needs `CONFIG_EC11=y`** (see
  `config/thenar.conf` and docs/known-issues.md).
- **Verify a rebuild actually changed the binary** before re-flashing
  to chase a symptom: `sha256sum` the old and new UF2s. Identical
  hashes mean your change didn't reach the build (see the two traps
  above).

## 3D printed case

A 3D-printable switch mid-plate is available: `nix build
.#switchplate-stl` produces a 1.3 mm plate (Choc clip depth) with
switch cutouts, scrollwheel cutout, and screw holes. Print two, mirror
one in the slicer. FDM cutouts come out slightly undersized; if
switches won't clip in, bump `switchplate_switch_cutout` to 14.2 in
`thenar/ergogen/config.yaml` and rebuild.

A full case is TODO — note: the upstream corax54 case will not fit
thenar without modification, because the outer column has an extra key.
Either redesign from `outlines/case.dxf` (produced by `nix build
.#scaffold`) or extend the upstream case in CAD.

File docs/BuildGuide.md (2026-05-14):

# Build Guide

> **⚠️ This guide is LLM-generated and has not been verified by an actual
> build.** It was produced by Claude by adapting the upstream
> [corax build guide](https://github.com/dnlbauer/corax-keyboard/blob/main/docs/BuildGuide.md) —
> rewording the prose, updating counts (54 → 56 keys, 28 hotswaps + 29
> diodes per side), and replacing the upstream's image-per-step photos
> with text descriptions. The procedural content is paraphrased from the
> upstream guide rather than independently verified. Treat it as a
> starting point; expect to cross-reference the upstream guide and other
> ZMK split builds, and submit corrections after your first build.
>
> TODO: Replace prose with photos at each step. Sections for the Nice!View
> display and the 3D-printed case are still unwritten — the upstream guide
> left them as TODOs too.

Thenar's assembly is mechanically identical to the corax — same reversible
PCB, same MCU/scrollwheel/display layout — it just has one extra switch
position per half on the outermost column.

---

## Disclaimer

This guide is written from the perspective of someone who has already built
some keyboards. It is probably not very beginner-friendly. There are many
tricks and techniques for soldering and assembling keyboards that are not
covered in detail. If this is your first build, I strongly recommend reading
one or two more comprehensive guides on other keyboards first. A great one
to start with is the Sofle guide:
<https://josefadamcik.github.io/SofleKeyboard/build_guide_choc.html>

## PCB routing (one-time, before you can order)

> **⚠️ The committed PCB in `thenar/routed/` is currently a verbatim copy
> of the ergogen scaffold — it has all the footprints placed but no copper
> routing.** Building gerbers from it today produces an unfabricatable
> board. Someone has to route the traces by hand in KiCad before any
> useful gerbers can be produced. See `thenar/routed/README.md` for
> current status.

If you are the one doing the routing, see the dedicated
[Routing Guide](./RoutingGuide.md) for the step-by-step. The short
version:

```sh
nix build .#scaffold
# Open result/pcbs/keyboard.kicad_pcb in KiCad and route every net.
# Save your routed version over thenar/routed/keyboard.kicad_pcb.
# (Repeat for switchplate if any changes are needed.)
nix flake check        # confirms footprint placement still matches the scaffold
```

If someone else has already routed and committed (the normal case once
this stabilises): skip this section, go straight to ordering.

## Ordering PCBs

Build the gerber zip from the flake:

```sh
nix build .#gerbers-zip
```

`result/thenar-gerbers.zip` is the file you upload to your PCB fab. I
recommend [JLCPCB](https://jlcpcb.com/) with these settings:

| | |
|---|---|
| Layers | 2 |
| PCB Thickness | 1.6 mm |
| Surface Finish | LeadFree HASL |
| Via Covering | Tented |
| Board Outline Tolerance | +/- 0.2 mm (Regular)|

## Building the keyboard

You need two PCBs — one for each hand. The PCB is reversible, so the same
board is used for both halves; the side you treat as the front determines
which hand the half becomes.

If this guide says "front side" and you are building the left half, you
work on the side that has **"Left Hand Front"** silkscreened on it. The
side with "Right Hand Front" is then the back side for that half. The
right half is the opposite: "Right Hand Front" is its front, "Left Hand
Front" is its back.

A good strategy is to mark the intended front side of each half with a
piece of tape or a post-it before you start. Check before every step that
you are working on the correct side.

### Jumpers

There are 12 jumpers on each side of the board, in three groups (MCU,
display, scrollwheel). They make the MCU/display/encoder footprints
reusable between the two halves by letting you pick which side connects
each net.

**Solder the jumpers ONLY on the back side of the PCB.** That is: when
building the left half (front labelled "Left Hand Front"), solder the
jumpers on the "Right Hand Front" side. This is critical — soldering on
the wrong side will not work, and on the MCU jumpers in particular it
can short pins together and destroy the Nice!Nano on power-up.

Bridge each jumper with a small blob of solder across the two pads.

### MCU sockets

Solder the 12-pin sockets for the Nice!Nano. The sockets go on the front
side. A useful trick is to tape the sockets in position from the front,
flip the board, and solder them from the back while the tape holds them
flush.

If you want the LiPo battery to fit between the PCB and the MCU later,
use low-profile sockets (e.g. 3DS1002-01-1\*20V13-JK by CONNFLY) — and
see Splitkb's mounting guide for a thorough walkthrough of how to height
the MCU sockets correctly:
<https://docs.splitkb.com/hc/en-us/articles/360011263059>

### On/Off switch and reset button

The on/off slider switch (C128955) goes on the **back side** of the
board. This leaves clearance on the front for the battery to sit between
the PCB and the MCU. The switch has 7 legs but only the 3 marked legs
are electrically required — soldering the other tabs as mechanical
support is optional.

The 2-pin reset button goes on the **front side**: insert it from the
front and solder the legs on the back. Orientation does not matter.

### Scrollwheel

Before soldering the EVQWGD001 encoder, you need to trim some of its
legs and tabs so it fits the PCB cleanly:

- Cut off the foot on the left side of the encoder (looking at the
  encoder from the wheel side) — there is no matching hole for it on
  the PCB.
- Trim the overhang tabs along the long right edge of the encoder. The
  signal pins alone are sturdy enough to hold it in place, and trimming
  these makes the encoder much easier to seat without flexing or
  snapping a pin.

Place the encoder on the board (front side) and solder its pins from
the back.

### Hotswap sockets and diodes

There are **28 Kailh Choc v1 hotswap sockets** and **29 diodes** (1N4148W
SMD) per side — one diode per switch plus one for the scrollwheel. Both
the sockets and the diodes are mounted on the **back side** of the board.

Diode orientation matters. Each 1N4148W has a marking (an arrow or a
white line) on one end indicating the cathode. Align that mark with the
arrow on the silkscreen for each diode footprint. If you are unsure how
to read diode polarity, look it up before placing any — flipped diodes
will silently break the matrix for the affected key.

Workflow that tends to work well: tin one pad of each footprint first
(diodes and hotswaps both), then place the part with tweezers and
reflow that pad to anchor it, then solder the remaining pad(s). For
the hotswaps, press the socket flat against the PCB while reflowing
the anchor pad — gaps cause inconsistent key heights and bad switch
seating.

### Battery

Solder the LiPo battery (301230, 110 mAh) to the front-side battery pads
below the MCU footprint. The pads are labelled `+` and `-` on the
silkscreen; black wire goes to `-`, red wire goes to `+`. Double-check
polarity with a multimeter before powering on — a reversed LiPo will
damage the Nice!Nano (and possibly catch fire).

The battery is intended to sit on the front side, tucked under the MCU.
You can mount it on the back instead if you prefer; the pads work either
way as long as polarity matches the silkscreen.

### MCU

Add the Nice!Nano and solder the pins on the MCU side. The MCU sits on
the **front side, facing down** (components toward the PCB). If you
chose low-profile sockets, there should be enough room for the battery
to live underneath. If not, position the pins so the gap is large
enough — solder the first and last pin to set the height, check
clearance, then solder the rest.

### Switches and keycaps

Snap the Kailh Choc v1 switches (PG1350) into the hotswap sockets from
the front side. If you are using a switchplate, install it before the
switches — the switches clip into the plate first, then the whole
assembly presses down into the sockets.

Add keycaps.

## Display (Nice!View)

TODO

## 3D printed case

TODO — and note: the upstream corax54 case will not fit thenar without
modification, because the outer column has an extra key. Either redesign
from `outlines/case.dxf` (produced by `nix build .#pcbs`) or extend the
upstream case in CAD.

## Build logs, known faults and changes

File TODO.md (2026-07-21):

# Thenar — outstanding work

Snapshot of everything left as of 2026-07. The keyboard **works today**
(both halves, both encoders, full keymap, wireless) — everything below
is improvement/rework, not "it's broken." Cross-refs point at the docs
that have the detail.

## Hardware rework — the rev1 board in hand

- [ ] **Move the LiPo from RAW → nice!nano B+/B-.** As-fabbed, the
      battery is on RAW, so it reads a flat **0%** and **USB won't charge
      it**. Solder the cell to the module's B+/B- pads (it sits in the gap
      under the socketed module), off the JST/slider/RAW path. Restores
      battery sensing + USB charging. → `docs/battery-and-power.md` (rev1
      rework). Charge the cell externally until this is done.
- [ ] **(Optional) Rewire the slider to P0 for soft-off** — if you want
      the switch back as an on/off (µA sleep, still charges). Otherwise
      the slider goes dead after the rework and idle deep-sleep covers
      "off". → same doc, "advanced" rework.

## rev2 PCB — for the next fab (ergogen source is already rev2)

- [ ] **Delta-patch `thenar/routed/keyboard.kicad_pcb` in KiCad.** The
      ergogen source is rev2 (battery→`BAT_BPLUS`, slider→`SOFT_OFF`/P0)
      but the routed board is still rev1, so the flake `routing-check` is
      **RED** until this lands. The delta is tiny — 4 pad-net reassigns +
      delete 2 traces + route 1 trace + silk + DRC. Exact recipe (net
      table) in `docs/battery-and-power.md` → "Reroute recipe (Path A)".
      Autoroute fallback = `nix build .#routed-auto`.
- [ ] After patching, commit the routed board → `routing-check` goes
      green → export gerbers → fab rev2 if/when you want new boards.

## Firmware

- [ ] **Apply the soft-off scaffold** (`CONFIG_ZMK_PM_SOFT_OFF` + the P0
      wakeup-GPIO node) once a board actually has the slider on P0, then
      bench-test soft-off + charge-while-off. Kept out of active firmware
      until testable. → `docs/battery-and-power.md` (rev2 firmware).

## Desktop integration (dragon / DankMaterialShell)

- [ ] **DMS `isLaptopBattery` patch** so the keyboard battery renders in
      the bar. `upower` already exposes the Thenar (PR #789 merged); DMS
      filters UPower devices to laptop batteries only, so peripherals are
      dropped. Patch `dotfiles/dms` to surface non-laptop batteries.
      Only meaningful after the B+/B- rework makes it report a real %.

## Leisure / finishing

- [ ] Print the switch plate + case (STLs current; all cutouts fixed).
- [ ] Conformal-coat for spill resistance → `docs/spill-protection.md`
      (mask list included). Do it *after* the battery rework — it's a
      finishing step, not a bring-up one.

## Done (for reference — no action)

Encoder (both rotation + press), the full Iris + Miryoku keymap,
Config-gated Miryoku entry, reliable Lower+Config→Nav tri-layer, +8 dBm
TX power for wireless latency, bootloader-recovery flashing — all landed
and committed on `main`. rev1 is frozen at tag `hw-rev1`.

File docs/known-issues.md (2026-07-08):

# Known issues / deviations

Things found during actual builds that should be fixed in a future PCB
revision. Each entry lists what bit, where it lives in the codebase, and
the workaround for the current revision.

## v1.0 — present rev

### Scrollwheel mounting peg has no hole

**Symptom**: The Panasonic EVQWGD001 encoder has a small plastic
alignment peg on its underside (in addition to the 6 electrical pins).
The current footprint provides through-holes for the pins and an
Edge.Cuts slot for the encoder body — but **no NPTH for the plastic
peg**. Builders have to trim the peg off with flush cutters before the
encoder will sit flush.

**Where**: `thenar/ergogen/footprints/scrollwheel_mirrored.js` — the
`pins(...)` function adds the electrical THT pads and Edge.Cuts but
doesn't add an NPTH for the peg.

**Current workaround**: Trim the peg before placing the encoder. The
build guide (`docs/build.md`, "Scrollwheel" section) already mentions
this as "cut off the foot on the left side of the encoder."

**v2 fix**: Add an `np_thru_hole` at the peg's coordinate (need to
measure on a real encoder; the EVQWGD001 datasheet lists mechanical
dimensions but the peg location isn't always shown). Size around
1.2 mm diameter should be enough.

### Screw holes are plated and one merges with the 5-key pad

**Symptom**: The inner-num key ("5" on the left half) doesn't register.
The top-right screw hole is a *plated* through-hole (PTH) whose copper
annulus physically touches the switch's down-side hotswap pad (DRC:
`PTH pad [<no net>] of _5` vs `Pad 2 [inner_num] of S26`). Two failure
modes: (1) the huge copper ring acts as a heat sink fused to the pad,
so the hotswap socket joint goes cold during soldering — this is what
actually bit; (2) a metal screw + standoff chain through that hole can
ground the switch net.

**Where**: `thenar/ergogen/footprints/hole.js` emits a plated pad; the
`screw_top_right` zone anchor in `thenar/ergogen/config.yaml` places it
too close to `matrix_inner_num`.

**Current workaround**: Solder that hotswap socket with extra heat and
dwell time (the ring steals heat). Prefer a nylon screw or washer at
that position.

**v2 fix**: Make the hole footprint NPTH (no copper), and/or move the
`screw_top_right` anchor a couple mm away from the key. The same `hole.js` wrapper was copied into the hypothenar repo
(github.com/lytedev/hypothenar-keyboard) — fix it there too.

### EVQWGD001 rotation needs CONFIG_EC11 (fixed, kept for the record)

**Symptom**: Encoder press works but rotation does nothing, with
perfect continuity on all three signal legs. The `alps,ec11`
devicetree nodes alone do NOT pull in the driver — without
`CONFIG_EC11=y` the firmware builds cleanly and rotation is silently
dead.

**Fix (in tree)**: `config/thenar.conf` sets `CONFIG_EC11=y` and
`CONFIG_EC11_TRIGGER_GLOBAL_THREAD=y`. If rotation ever dies again
after config surgery, first check that file still exists and that the
build log contains `ZMK Config Kconfig: .../config/thenar.conf` and
`ec11.c.obj`.

### Right half "all 28 diodes reversed" was a misdiagnosis — the diodes AND the silk were correct; the old right-half firmware scanned backwards

**Symptom (as observed at the time)**: On the right half (the same
reversible PCB flipped over), every key was dead — zero keys scanned —
while the encoder worked fine. A bench experiment then appeared to
convict the diodes: a diode installed with its band *opposite* the
soldering face's silk scanned, while diodes following the silk did not
conduct "in the scan direction". Two sessions of analysis flip-flopped
between "the back silk is unmirrored and therefore wrong" and "the silk
is correct, the assembly is reversed" (the previous version of this
entry). **Both causal stories were wrong.**

**What was actually broken**: the pre-`fdf3b3df`
`thenar_right.overlay` had the kscan pin roles swapped. Per the ZMK
driver source (`kscan_gpio_matrix.c`: for `diode-direction = "col2row"`
the macro `COND_DIODE_DIR` makes `.inputs = row-gpios` and
`.outputs = col-gpios` — i.e. **row-gpios are SENSED, col-gpios are
DRIVEN**, which is also why stock shields like the corne put the
pull-downs on row-gpios), the old right overlay *drove* pins 9/8/7/6/5/4
(nets col4..col0 plus the display CS line) and *sensed* pins
18/15/14/16/10 (nets row1..row5). That is exactly backwards from the
board's diode direction, so:

- every correctly-installed diode blocked the (reversed) scan current →
  zero keys, encoder unaffected;
- the one diode deliberately flipped during debugging conducted in that
  reversed direction → "band opposite the silk works", the observation
  that spawned the reversed-diodes myth.

A contributing confusion that survives in the overlay comment blocks:
they label row-gpios as "driven outputs" and col-gpios as "sensed
inputs". **Those comments are backwards** relative to the driver (fix
pending — out of scope for the change that corrected this entry).

**What the silk actually indicates**: the correct cathode end, on
**both** faces, including already-fabbed v1.0 boards. Derivation from
the generated netlist: diode pad 1 (x=-1.65, present on F.Cu and B.Cu)
carries the `to`/row_net (col0..col4 — the nets on MCU pins 5-9, the
sensed row-gpios); pad 2 carries the per-key `colrow` net to the
switch and on to the driven row0..row5 nets. Scan current runs
driven rowN → switch → colrow → diode → sensed colN, so the cathode
belongs at pad 1 — and the silk bar (x=-0.35) sits adjacent to pad 1
on both F.SilkS and B.SilkS. Renders of the front face and the
mirrored back face both show the arrow pointing at, and the bar/K
marking, the pad-1/colN end. No face of any fab has misleading silk.

**The rule (one sentence)**: On either face of the board, solder every
matrix diode with its cathode band at the end marked by that face's
silk bar / arrow tip (the end labeled "K" on post-v1.0 fabs) — the pad
wired to a col0..col4 net — and never orient by comparing against the
other half or a front-view render (correctly built halves LOOK
mirrored to each other).

**Current state / workaround**: none needed for assembly — follow the
silk. Do **not** apply this entry's previous workaround ("rotate all
28 right-half diodes 180°"): the installed diodes were never reversed
(the post-fix firmware types through them, which is only electrically
possible with bands at the bar end), and rotating them would kill
every key. If the single band-opposite test diode from the bring-up
experiment is still installed, flip it back to match the silk — its
key is dead under the corrected firmware.

**Hardening (in tree)**: `thenar/ergogen/footprints/diode.js` adds a
small "K" cathode letter next to the bar on both faces (the B.SilkS
copy is `justify mirror`ed so it reads as a proper K from the back),
and now carries the full polarity derivation in a comment. v1.0 PCBs
predate the K; use the bar/arrow-tip rule above.

---

(Add new deviations above this line as they're found.)

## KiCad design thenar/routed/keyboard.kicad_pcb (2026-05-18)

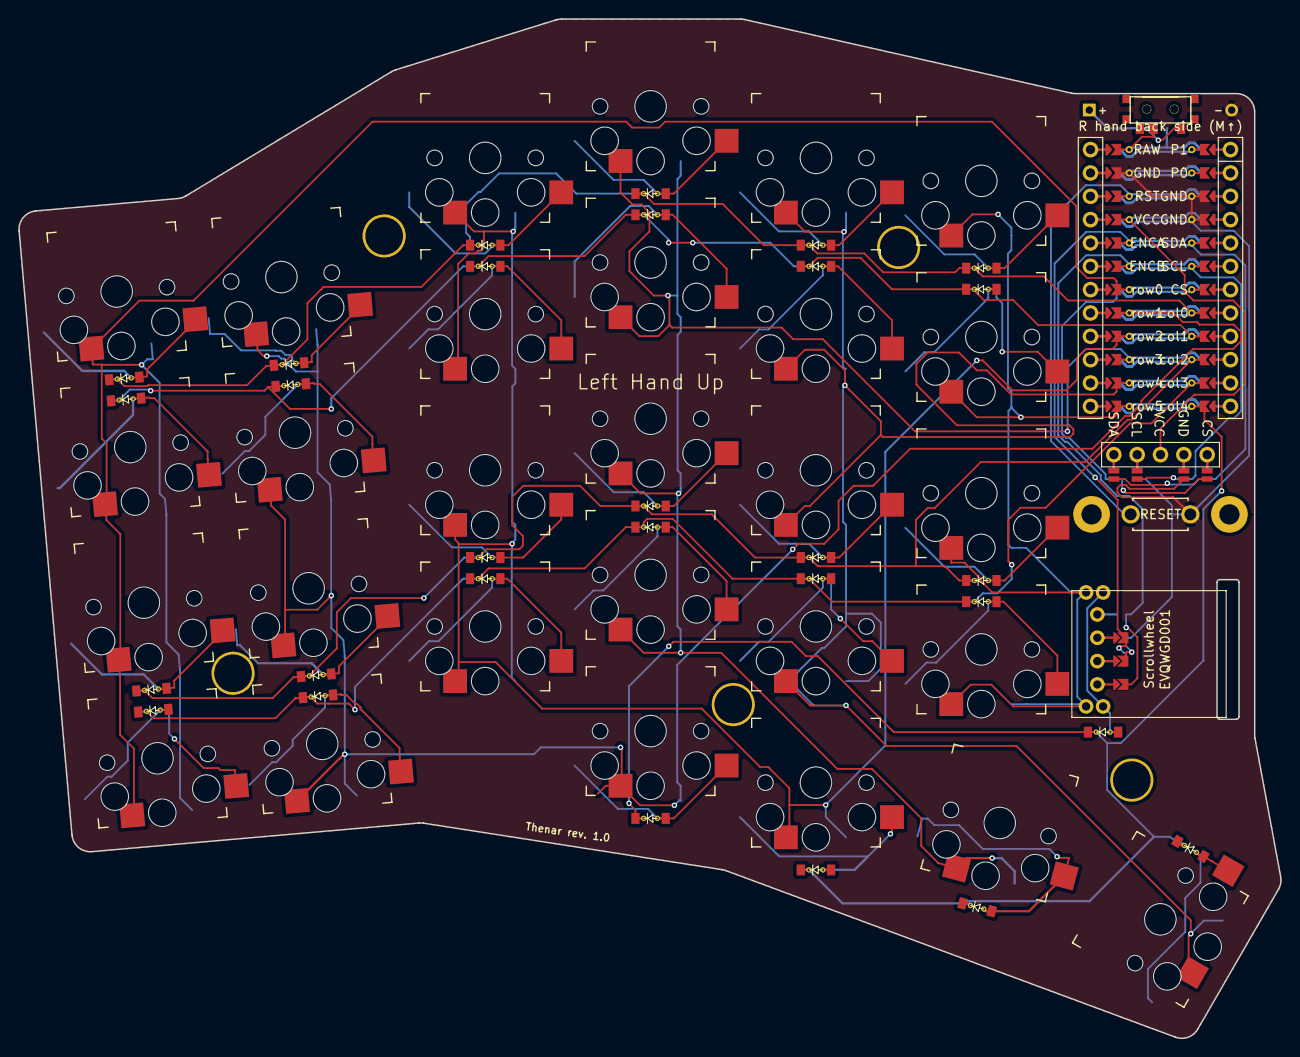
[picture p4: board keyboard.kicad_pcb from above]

Board: 2 copper layers, 137.3 x 110.9 mm, 74 parts (0 on the bottom side), 54 nets.

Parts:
D1, D2, D3, D4, D5, D6, D7, D8, D9, D10, D11, D12, D13, D14, D15, D16, D17, D18, D19, D20, D21, D22, D23, D24, D25, D26, D27, D28, D29: ComboDiode
DISP1: display_nice_view
J1, J2, J3, J4, J5, J6: Jumper
MCU1: mcu_nice_nano
S1, S2, S3, S4, S5, S6, S7, S8, S9, S10, S11, S12, S13, S14, S15, S16, S17, S18, S19, S20, S21, S22, S23, S24, S25, S26, S27, S28: PG1350
T1: SPDT_C128955
_1: ResetSW
_2, _3, _4, _5, _6, _7, _8: Hole

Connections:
CS: DISP1.14, DISP1.24, MCU1.107
DISP1_1: DISP1.1, DISP1.10, DISP1.23
DISP1_2: DISP1.2, DISP1.11, DISP1.22
DISP1_4: DISP1.4, DISP1.12, DISP1.21
DISP1_5: DISP1.5, DISP1.13, DISP1.20
ENCA: J3.2, J6.2, MCU1.120
ENCB: J1.2, J4.2, MCU1.119
GND: DISP1.15, DISP1.25, J2.2, J5.2, MCU1.103, MCU1.104, MCU1.123, _1.2
RAW: MCU1.124, T1.2
RST: MCU1.122, _1.1
SCL: DISP1.16, DISP1.26, MCU1.106
SDA: DISP1.17, DISP1.27, MCU1.105
VCC: DISP1.3, MCU1.121
col0: D2.1, D4.1, D6.1, D9.1, D12.1, D14.1, MCU1.108
col1: D17.1, D19.1, D21.1, D23.1, D25.1, D27.1, MCU1.109
col2: D1.1, D3.1, D5.1, D8.1, D11.1, D13.1, MCU1.110
col3: D16.1, D18.1, D20.1, D22.1, D24.1, D26.1, MCU1.111
col4: D7.1, D10.1, D15.1, D28.1, D29.1, MCU1.112
index_bottom: D24.2, S19.2
index_home: D11.2, S20.2
index_mod: D10.2, S18.2
index_num: D12.2, S22.2
index_top: D25.2, S21.2
inner_bottom: D26.2, S23.2
inner_home: D13.2, S24.2
inner_num: D14.2, S26.2
inner_top: D27.2, S25.2
layer_cluster: D15.2, S27.2
middle_bottom: D22.2, S14.2
middle_home: D8.2, S15.2
middle_mod: D7.2, S13.2
middle_num: D9.2, S17.2
middle_top: D23.2, S16.2
outer_bottom: D16.2, S1.2
outer_home: D1.2, S2.2
outer_num: D2.2, S4.2
outer_top: D17.2, S3.2
pinky_bottom: D18.2, S5.2
pinky_home: D3.2, S6.2
pinky_num: D4.2, S8.2
pinky_top: D19.2, S7.2
ring_bottom: D20.2, S9.2
ring_home: D5.2, S10.2
ring_num: D6.2, S12.2
ring_top: D21.2, S11.2
row0: MCU1.118, S1.1, S2.1, S3.1, S4.1
row1: MCU1.117, S5.1, S6.1, S7.1, S8.1, S13.1
row2: MCU1.116, S9.1, S10.1, S11.1, S12.1, S18.1
row3: MCU1.115, S14.1, S15.1, S16.1, S17.1, S27.1
row4: MCU1.114, S19.1, S20.1, S21.1, S22.1, S28.1
row5: MCU1.113, S23.1, S24.1, S25.1, S26.1
space_cluster: D28.2, S28.2
sw_b: J2.1, J6.1
sw_c: J3.1, J5.1

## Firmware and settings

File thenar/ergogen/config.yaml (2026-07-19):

units:
  kx: cx  # cx=18
  ky: cy  # cy=17
  mbkx: 17.5
  mbky: 16.5
  padding: 2
  px: kx+padding
  py: ky+padding
  mcu_height: 34
  mcu_width: 18
  # distance keys to mcu
  mcu_padding: 1.5
  scrollwheel_width: 17
  scrollwheel_height: 14
  screw_diameter: 4.7
  screw_hole: 4.1
  screen_screw_diameter: 4
  screen_screw_hole: 2.2
  switchplate_switch_cutout: 14
  # EVQWGD001 clearance, from the RollerEncoder footprint envelope: body
  # silk x -8.4..8.4 / y +-7.4 (union of both reversible mounts) plus the
  # wheel slot reaching x 9.8 / y +-7.6 on the +x (wheel) side. Margins
  # are >=1mm per side; the wheel side runs to 12.5 so the cutout opens
  # through the plate's outer edge at +11.5 (a closed rim there would be
  # a <1mm unprintable sliver).
  switchplate_scrollwheel_pad_side: 9.4
  switchplate_scrollwheel_wheel_side: 12.5
  switchplate_scrollwheel_cutout_y: 17.2
  switchplate_screw_diameter: 3.3
  switchplate_screw_hole: 2.2
  # Reset button access notch. The kbd:ResetSW body+pads span 8.5x3.5mm
  # centred 27mm from the mcu point, only ~1mm clear of the plate edge at
  # nominal - found interfering on the first assembled unit. 12x9 centred
  # on the button leaves >=1.75mm per side and deepens the MCU notch edge
  # by ~1.8mm for finger/tweezer access.
  switchplate_reset_cutout_x: 12
  switchplate_reset_cutout_y: 9
points:
  rotate: 5
  zones:
    matrix:
      # fix placement on kicad
      anchor.shift: [50, -150]
      key:
        tags: [switch]
        padding: 1ky
        spread: 1kx
      columns:
        outer:
          rows:
            mod.skip: true
          key:
            column_net: row0
        pinky:
          rows:
            mod.skip: true
          key:
            origin: [0, 8]
            column_net: row1
        ring:
          rows:
            mod.skip: true
          key:
            origin: [0, 8]
            stagger: 0.66ky
            splay: -5
            column_net: row2
        middle:
          key:
            stagger: 0.33ky
            column_net: row3
          rows:
            mod:
              column_net: row1
        index:
          key:
            stagger: -0.33ky
            column_net: row4
          rows:
            mod:
              column_net: row2
        inner:
          rows:
            mod.skip: true
          key:
            stagger: -2.5
            column_net: row5
      rows:
        mod:
          row_net: col4
          tags: [switch_bottom]
        bottom:
          row_net: col3
          tags: [switch_top]
        home:
          row_net: col2
          tags: [switch_bottom]
        top:
          row_net: col1
          tags: [switch_top]
        num:
          row_net: col0
          tags: [switch_bottom]
    thumbs:
      anchor:
        ref: matrix_middle_home
        shift: [38, -44]
      key:
        tags: [switch]
        padding: 1ky
        spread: 1kx
      columns:
        layer:
          key:
            splay: -15
            column_net: row3
        space:
          key:
            width: 1.5kx
            splay: 75
            shift: [13-kx, -3]
            column_net: row4
            tags: [switch_space]
      rows:
        cluster:
          row_net: col4
    scrollwheel:
      anchor:
        ref: matrix_inner_bottom
      columns:
        scrollwheel:
          key:
            tags: [scrollwheel]
            shift: [kx+mcu_padding-1.25, 0]
            column_net: row5
            width: scrollwheel_width
            height: scrollwheel_height
      rows:
        scrollwheel:
          row_net: col4
    mcu:
      anchor:
        ref: matrix_inner_num
      columns:
        mcu:
          key:
            tags: [mcu]
            width: mcu_height  # footprint width/height unintuitive
            height: mcu_width
            rotate: -90
            shift: [kx+mcu_padding, -mcu_width/2-0.3]
    screw_top_left:
      anchor:
        ref.aggregate.parts: [matrix_ring_num, matrix_ring_top]
        shift: [-11, 0]
      columns.screw.key.tags: [screw]
    screw_top_right:
      anchor:
        ref.aggregate.parts: [matrix_index_num, matrix_inner_num, matrix_index_top, matrix_inner_top]
      columns.screw.key.tags: [screw]
    screw_bottom_left:
      anchor:
        ref.aggregate.parts: [matrix_outer_home, matrix_outer_bottom, matrix_pinky_home, matrix_pinky_bottom]
      columns.screw.key.tags: [screw]
    screw_bottom_right:
      anchor:
        ref.aggregate.parts: [matrix_index_bottom, matrix_index_mod]
        shift: [-0.5kx, 0]
      columns.screw.key.tags: [screw]
    screw_thumb:
      anchor:
        ref.aggregate.parts: [thumbs_layer_cluster, thumbs_space_cluster]
        shift: [9, 7]
      columns.screw.key.tags: [screw]
outlines:
  board:
    - what: polygon
      operation: stack
      fillet: 2
      points:
        - ref: matrix_outer_home
          shift: [-0.5px, -0.5py]
        - ref: matrix_outer_home
          shift: [-0.5px, 0.5py]
        - ref: matrix_outer_top
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

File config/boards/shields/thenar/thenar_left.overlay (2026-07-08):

#include "thenar.dtsi"

&physical_layout0 {
    kscan = <&kscan0>;
    transform = <&default_transform>;
};

&kscan0 {
    diode-direction = "col2row";

    // SENSED INPUTS (hence the pull-downs). Driver-verified: with
    // diode-direction col2row, kscan_gpio_matrix.c makes row-gpios the
    // .inputs and col-gpios the .outputs - the OPPOSITE of what this
    // comment used to claim. These pins carry the col0..col4 nets (one
    // per visual row: num/top/home/bottom/mod).
    row-gpios
        = <&pro_micro 5 (GPIO_ACTIVE_HIGH | GPIO_PULL_DOWN)>  // col0 (num)
        , <&pro_micro 6 (GPIO_ACTIVE_HIGH | GPIO_PULL_DOWN)>  // col1 (top)
        , <&pro_micro 7 (GPIO_ACTIVE_HIGH | GPIO_PULL_DOWN)>  // col2 (home)
        , <&pro_micro 8 (GPIO_ACTIVE_HIGH | GPIO_PULL_DOWN)>  // col3 (bottom)
        , <&pro_micro 9 (GPIO_ACTIVE_HIGH | GPIO_PULL_DOWN)>  // col4 (mod + thumb + scrollwheel)
        ;

    // DRIVEN OUTPUTS (see above - the old comment had drive/sense
    // backwards). These carry the row0..row5 nets (one per finger
    // column: outer/pinky/ring/middle/index/inner). Diode cathodes
    // face the col0..col4 nets = the silk bar / K end.
    col-gpios
        = <&pro_micro 19 GPIO_ACTIVE_HIGH>  // row0 (outer)
        , <&pro_micro 18 GPIO_ACTIVE_HIGH>  // row1 (pinky)
        , <&pro_micro 15 GPIO_ACTIVE_HIGH>  // row2 (ring)
        , <&pro_micro 14 GPIO_ACTIVE_HIGH>  // row3 (middle)
        , <&pro_micro 16 GPIO_ACTIVE_HIGH>  // row4 (index)
        , <&pro_micro 10 GPIO_ACTIVE_HIGH>  // row5 (inner)
        ;
};

&encoder_left {
    status = "okay";
};

&pinctrl {
    spi0_default: spi0_default {
        group1 {
            psels = <NRF_PSEL(SPIM_SCK, 0, 20)>,
                <NRF_PSEL(SPIM_MOSI, 0, 17)>,
                <NRF_PSEL(SPIM_MISO, 0, 25)>;
        };
    };
    spi0_sleep: spi0_sleep {
        group1 {
            psels = <NRF_PSEL(SPIM_SCK, 0, 20)>,
                <NRF_PSEL(SPIM_MOSI, 0, 17)>,
                <NRF_PSEL(SPIM_MISO, 0, 25)>;
            low-power-enable;
        };
    };
};

nice_view_spi: &spi0 {
    compatible = "nordic,nrf-spim";
    pinctrl-0 = <&spi0_default>;
    pinctrl-1 = <&spi0_sleep>;
    pinctrl-names = "default", "sleep";
    cs-gpios = <&pro_micro 4 GPIO_ACTIVE_HIGH>;
};

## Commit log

2026-05-14 feat: fork to thenar keyboard
    Rename project from corax to thenar (a 56-key variant adding a num-row key
    to the top of each outer column).
    - Remove corax54/ and corax56/ variants
    - Remove corax-specific images, build guide, and 3d/gerber artifacts
    - Add thenar/ergogen config (corax54 base + outer column num row unskipped,
    outline extended to cover the new key)
    - Replace build.ninja + npm with a flake providing pcbs / gerbers / gerbers-zip
    / switchplate-step packages and a devShell with ergogen + kicad + zip
    - Rewrite top-level README and add TODO stubs for build guide and ZMK config
    [board.dxf, case.dxf, case.f3z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]
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2026-05-14 docs: rewrite build guide based on upstream corax guide
    Replaces my earlier from-scratch draft. The new version is paraphrased
    from the real upstream corax build guide with counts (28 hotswaps + 29
    diodes per side) and naming adjusted for thenar. Clearly labelled as
    LLM-generated and unverified.
    Also drops the zmk-config submodule (pointed at the upstream
    corax-zmk-config repo, irrelevant for thenar) and its .gitmodules entry.
2026-05-14 feat: split scaffold/routed phases for the PCB build
    Ergogen produces footprints + nets but no copper traces. Manual KiCad
    routing is unavoidable, so model that explicitly:
    - thenar/routed/ holds the hand-routed PCB (committed). Seeded as a
    verbatim copy of the scaffold; clearly marked as unrouted until someone
    actually routes it.
    - .#scaffold (was .#pcbs) produces the ergogen scaffold for hand-routing
    - .#gerbers and .#switchplate-step now read from thenar/routed/, not from
    the ergogen scaffold
    - .#check-routing-drift compares footprint placement between the scaffold
    and thenar/routed/ via kicad-cli pos exports; wired into flake checks
    - README and BuildGuide spell out the two path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
    [keyboard.kicad_pcb, switchplate.kicad_pcb]
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2026-05-14 feat: clarify reversible-PCB orientation with 'up'/'down' instead of 'front'/'back'
    Silkscreen: 'Left Hand Front' / 'Right Hand Front' -> 'Left Hand Up' /
    'Right Hand Up'. 'Front' was overloaded with the keyboard sense of 'row
    closest to the user' and obscured what the label actually means: which
    face of the reversible PCB ends up pointing toward the user's fingers.
    - Rename text in thenar/ergogen/config.yaml
    - Rewrite build.md to use 'up side' / 'down side' throughout
    - Re-seed thenar/routed/ from the new scaffold (text is a footprint, so
    the rename triggered routing-drift; placement is otherwise unchanged)
    [keyboard.kicad_pcb]
2026-05-14 feat: generate .kicad_pro with design rules in the scaffold
    Ergogen only emits .kicad_pcb, so the kicad launcher refused to open it
    ('does not appear to be a KiCad project file'). Add a small Python script
    that writes a sibling .kicad_pro with sensible defaults for hand-routed
    two-layer choc keyboards:
    - Default class: 0.25mm tracks, 0.6mm vias, 0.2mm clearance
    - Power class: 0.40mm tracks, 0.8mm vias (VCC, GND, BAT+, RAW, VBUS)
    - Min clearance 0.2mm, min track 0.2mm, min via 0.6/0.3mm
    The scaffold derivation runs it post-ergogen so the output now ships a
    kicad_pro alongside every kicad_pcb. Re-seed thenar/routed/ to match.
    Routing guide updated to use 'kicad' launcher and document th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
2026-05-14 fix(scaffold): use KiCad's own demo as .kicad_pro template
    My handwritten minimal kicad_pro was too sparse - KiCad 10's launcher
    opened it but showed 'Empty project' because it could not auto-discover
    the sibling .kicad_pcb. The launcher needs the full schema (~12
    top-level sections including pcbnew, schematic, libraries, sheets,
    text_variables, etc).
    Approach: copy KiCad's own ecc83 demo .kicad_pro as a template and
    patch only what we care about (project name, design rules, power-net
    class). KiCad now opens the project with all sibling files listed
    correctly.
    Also: stop generating a kicad_pro for the switchplate. The switchplate
    is an outline-only board (never hand-routed), and two .kicad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
2026-05-14 feat(ergogen): close the outline polygon at the outer-num corner
    The outline definition added matrix_outer_num top-LEFT followed by top-RIGHT
    between outer_top and pinky_num. Because pinky_num top-left is slightly LEFT
    of outer_num top-right (pinky column is +1kx, but the polygon shift offsets
    collapse the gap to under 2mm), the polygon backtracks at that corner. With
    fillet=2 ergogen produces an outline with a non-closing gap there, breaking
    DSN export and tripping KiCad's invalid_outline DRC check.
    Fix: drop the redundant outer_num top-right point. The polygon now goes
    outer_top top-left -> outer_num top-left -> pinky_num top-left, the same
    left-edge-then-diagonal shape that worked for th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
    [keyboard.kicad_pcb, switchplate.kicad_pcb]
2026-05-14 feat(ergogen): migrate Nice!View to ceoloide's single-net-per-pad footprint
    The old corax-style niceview.js used the legacy reversible pattern with
    two pads numbered '1' on different nets (NN_GND_SCL and NN_CS_SDA), which
    KiCad reports as 'two nets shorting on the same pad' and breaks Specctra
    DSN export. Replace with ceoloide's display_nice_view (sourced from
    github.com/ceoloide/ergogen-footprints), which gives each pin a unique
    pad number and generates its own reversibility jumpers as separate SMD
    pads.
    Config changes:
    - Replace 'niceview' (custom) -> 'display_nice_view' (ceoloide)
    - Set reversible: true so the footprint emits jumpers
    - Drop 10 manual jumper_nv_{left,right}_* entries; ceo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
    [keyboard.kicad_pcb, switchplate.kicad_pcb]
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2026-05-14 fix(autoroute): split pcbnew calls into subprocesses + strip GND planes
    Two stabilizations to the autoroute pipeline:
    1. KiCad's swig pcbnew bindings segfault if you do LoadBoard + Export
    then later LoadBoard + Import + Save in the same Python process.
    Refactor autoroute.py so the export and import phases each run in
    their own subprocess (the script re-invokes itself with --export-dsn
    and --import-ses flags). The orchestrator process only does the
    pcbnew-free middle steps.
    2. KiCad exports the GND filled zones as Specctra '(plane GND ...)'
    blocks. Freerouting treats those as solid copper that blocks routing
    on most of both layers, so ~14 GND pads got reported as unrout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
2026-05-14 feat(ergogen): give scrollwheel pads unique local nets
    The encoder pads A/B/C/D were assigned hybrid net names (ENCB_undef,
    GND_ENCA, ENCA_GND, undef_ENCB) - one piece of copper carrying two
    different signals depending on which side of the reversible PCB the
    encoder is mounted on. Freerouting can't autoroute these because the
    'net' identity is ambiguous.
    Same fix pattern as the Nice!Nano migration, but at the config level
    (no footprint change needed): each encoder pad gets a UNIQUE local
    net (sw_a, sw_b, sw_c, sw_d) with one routing endpoint, and the
    existing jumper bridge between real signals (ENCA/ENCB/GND) and the
    local nets handles the per-side selection.
    Renaming for clarity:
    jumper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
    [keyboard.kicad_pcb, switchplate.kicad_pcb]
2026-05-14 feat(autoroute): use Global+Sequential strategy
    freerouting defaults (Greedy+Prioritized) plateau quickly. Switching to
    Global+Sequential produces identical final results but with cleaner
    behavior - no NullPointerException warnings on first-pass attempts, and
    freerouting actually completes the requested pass count instead of
    bailing early on score-improvement heuristics.
    This does NOT solve the underlying autoroute problem: the design still
    has ~28 unrouted items after a 30-pass run. Those items are in the
    dense areas (col4 matrix across the whole board, scrollwheel encoder
    to jumper short hops, slider switch power nets) where freerouting's
    greedy local optimization can't find routes that a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
    [keyboard.kicad_pcb, switchplate.kicad_pcb]
2026-05-14 pcb: hand-route the keyboard
    DRC: 0 unconnected items. Remaining DRC warnings are all pre-existing
    cosmetic issues from the upstream corax design (silk-over-copper from
    labels under the Nice!Nano body, solder-mask-bridge between adjacent
    LED/diode pads, intentionally-tight 0.1527mm clearance between solder
    jumper bridge pads on J1-J6, one stray screw-hole/switch-pad overlap
    on S26 from the original layout).
    Routing took ~all 293 nets from scratch on the freshly-generated
    scaffold (ceoloide footprints had already laid 200 internal traces for
    the Nice!Nano/Nice!View reversibility jumpers, so the matrix + signal
    routing was the rest).
    [keyboard.kicad_pcb, switchplate.kicad_pcb]
2026-05-15 feat(scripts): compare_routing.py + freerouting timeout
    compare_routing.py: per-net length/via diff between two routed PCBs.
    Used to compare a hand-routed PCB against autoroute output. Surfaces
    nets that the candidate routed inefficiently (more length, fewer vias)
    or didn't route at all (much shorter total than golden).
    autoroute.py: cap the freerouting subprocess at 2x expected runtime.
    freerouting v2.2.1 retries failed telemetry POSTs to a 501-returning
    endpoint for ~60min when its analytics server is down (which it is, in
    our nix sandbox or anywhere with restricted outbound networking). That
    made autoroute.py hang for an hour after freerouting itself had
    finished. The timeout prints a wa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
2026-05-18 docs(routing): document autoroute findings and hybrid workflow
    Replace the speculative 'design-dependent' autoroute section with
    concrete numbers from the actual runs:
    - ~91% routed, ~23 nets typically unrouted
    - Identifies which nets get stuck (col4, matrix rows, sw_*)
    - Documents the via-count gap (102 human vs 43 autoroute) and why
    via_costs tuning helps marginally but not enough
    - Lists the implementation gotchas (DSN-breaker footprints, plane
    stripping, v2.2.4 multithread quirks)
    - Describes the hybrid workflow: autoroute the easy ~91%, hand-finish
    the dense areas
    - Documents the compare_routing.py script for A/B-ing routings
2026-05-18 pcb: re-route from autoroute baseline -- 44 vias (was 102)
    Restarting from the freerouting v2.2.4 autoroute output and finishing
    the ~25 unrouted nets by hand. Net result vs the from-scratch hand
    route: same 0 unconnected items, ~2% longer total trace length, but
    less than half the vias.
    DRC: 0 unconnected. Remaining warnings are the same pre-existing
    cosmetic issues from the upstream design (silk-over-copper, the
    intentional 0.1527mm solder bridge clearance on J1-J6, one stray
    screw-hole overlap on S26).
    Drift check currently produces a false-positive (floating-point
    precision noise from the SES roundtrip vs ergogen output - sub-micron
    differences). To be addressed in a follow-up.
    [keyboard.kicad_pcb]
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2026-06-01 docs: track v1.0 deviations - scrollwheel mounting peg has no NPTH
    Builders have to trim the EVQWGD001's plastic alignment peg before
    the encoder will seat flush. The footprint provides electrical pads
    and an Edge.Cuts body slot but no non-plated through-hole for the peg.
    v2 should add the NPTH. Build guide already documents the trim
    workaround. Logging here so the fix doesn't get lost across PCB revs.
2026-06-01 docs(v1): design notes for chip-direct PCBA redesign
    Starting v1 branch from rc1 (current main). v1 is a redesign for
    JLCPCB pick-and-place assembly:
    - Discrete nRF52840 on the main PCB (no Nice!Nano module)
    - 2x MCP23017 I/O expanders per half, switch-per-pin topology (no diodes)
    - Chip antenna (Johanson 2450AT18B100E) for forgiving RF layout
    - USB-C with standard ESD protection
    - Adafruit nRF52 bootloader flashed once via SWD per board, then
    USB drag-drop works like the Nice!Nano
    - rc1 (main branch) stays as validated prototype reference
    This commit just records the design plan. Implementation - schematic,
    footprint vetting, PCB layout, ergogen config, ZMK board definition -
    follows. S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
2026-06-01 docs(v1): drop reversibility, two separate PCB designs
    PCBA economics flip the reversibility tradeoff. Hand-soldering paid for
    itself by sharing one PCB SKU; PCBA pays for duplicate footprints and
    jumper bridges regardless. Plus the discrete-chip BOM multiplies the
    jumper count vs rc1 (now also needs jumpers around USB-C, charge IC,
    I/O expander reset, etc.).
    Plan: one ergogen config with mirror directive, emits thenar-left.kicad_pcb
    and thenar-right.kicad_pcb as independent designs. Each one optimized
    for its half (MCU placement, USB-C orientation, RF clearance).
    Cost delta: ~$50-80 more for the first PCBA run (two design setups vs
    one), recovered after the first revision through saved it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
2026-06-01 docs(v1): correct BOM from LCSC verification pass
    My first-pass BOM had wrong C-numbers for almost every IC (the LCSC
    catalogue numbers I cited pointed at unrelated resistors and ADCs).
    Verified actual part numbers against JLCPCB's catalogue and updated.
    Corrected parts:
    - U1 nRF52840: C840628 -> C190794 (Extended)
    - E1 antenna: C503520 -> C2917717 (Extended)
    - U2/U3 MCP23017: C9678 -> C47023 (Extended)
    - U5 TLV70233: C144586 -> C110287 (Extended)
    - L1/L2 10uH inductor: C1046 -> C1035 (Basic)
    - Y1 32 MHz crystal: C32346 (was duplicated) -> C843260 (Extended)
    Tier surprises (correct PN, but Extended not Basic as I assumed):
    - U4 MCP73831, U6 USBLC6, J1 U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
2026-06-01 docs(v1): cost+power-optimize the BOM
    Three concrete swaps based on JLCPCB catalogue research:
    1. MS88SF3 nRF52840 module (C20416747) instead of bare nRF52840 +
    discrete antenna + 32MHz crystal + 32.768kHz crystal + crystal
    caps + DCDC inductors. Pre-certified BLE, identical power (same
    chip inside), eliminates the trickiest RF design risks, and saves
    3 Extended setup fees by consolidating ~7 discrete parts into one
    module.
    2. XC6206P332MR LDO (C5446, BASIC tier) instead of TLV70233. Drops a
    $3 Extended setup fee, halves the piece price, AND improves
    quiescent current 10x (31 uA -> 1-3 uA). Biggest single win in the
    BOM - lower cost and better power simultaneously.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
2026-06-01 docs(v1): identify reference designs to fork from
    Researched open-source nRF52840 ZMK projects. No exact match for our
    MS88SF3 + MCP23017 combo (expected - rare combination) but four
    projects together cover everything we need:
    - Ladniy/jiran-ble-lite: PRIMARY FORK BASE - KiCad source, split,
    Holyiot 18010 module (similar to MS88SF3), CERN-OHL-P license.
    Take: split mechanics, power tree, USB-C+charge, KiCad project
    structure. Replace: Holyiot footprint -> MS88SF3, matrix -> our
    ergogen scaffold with MCP23017 expanders.
    - crides/kleeb: KiCad symbol/footprint library with the only public
    MS88SF3 symbol I found. MIT licensed.
    - ebastler/zmk-designguide: reference schematics for nRF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
2026-06-02 fix(v1/ergogen): scaffold places all components and loads in KiCad
    Several bugs blocked a valid kicad_pcb from the auto-generated and
    hand-written footprints:
    1. The converter emitted plain-string defaults (P1: 'P1_NC'), which
    ergogen treats as a string param. p.P1.str was undefined and pads
    emitted literal 'undefined' as their net spec, so KiCad refused to
    load the board. Switched to { type: 'net', value: '<placeholder>' }
    so ergogen parses the value into a real net object. Applied the
    same fix to mcp23017.js's GPB0..7 / GPA0..7 (formerly undefined).
    2. The KiCad source contains ${REFERENCE} placeholders for the
    reference designator text; JS template lite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
    [config.yaml]
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2026-07-04 feat(print): OpenSCAD sources for 3D-printable switchplate + bottom case
    - switchplate.scad: extrudes the ergogen switchplate DXF to 1.3mm
    (Choc clip band) and subtracts the 5 mounting screw holes, which the
    PCB variant gets as footprints rather than as outline geometry.
    - case.scad: first-pass bottom tray - 2mm floor, 7mm perimeter wall
    from offset() of the board outline (0.25mm PCB fit clearance),
    countersunk through-floor screw holes, 14mm open-top USB-C notch at
    the MCU position. v2 TODOs in the header: slider + reset access,
    battery pocket, screw bosses.
    - switchplate_holes.py: parses ergogen --debug points.yaml and emits
    tagged point centres as an OpenSCAD vector (tag arg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
    [case.scad, switchplate.scad]
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2026-07-05 feat(print): FDM cutout compensation + calibration coupon for the switch plate
    Research on 3D-printed Choc plates: 14.0mm is the right nominal cutout
    (the 13.8mm Kailh spec is for laser-cut plates and is too tight even
    there), but FDM prints interior cutouts 0.1-0.3mm undersized, so a
    CAD-true print grips switches too hard - exactly what the first test
    print showed.
    Two compensation paths, slicer-side preferred:
    1. Slicer hole compensation (Cura 'Hole Horizontal Expansion',
    PrusaSlicer/Orca 'XY hole compensation'), typically 0.15-0.25mm.
    No rebuild needed.
    2. Model-side: switchplate.scad gains -D print_compensation=<mm>,
    implemented as offset(delta=-c) on the imported ou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
    [switchplate-cal.scad, switchplate.scad]
2026-07-06 refactor!: extract the pick-and-place redesign to its own repo (hypothenar)
    The boards being built and validated right now ARE the thenar keyboard;
    the JLCPCB pick-and-place redesign shares only the physical layout with
    it (different MCU, switch topology, PCB architecture, firmware board).
    Versioning it as 'thenar v1' implied an upgrade path that does not
    exist, so it is now a sibling model in its own repository:
    github.com/lytedev/hypothenar-keyboard
    (hypothenar: the pinky-side palm muscle pad - anatomically adjacent to
    the thenar, and not the same thing.)
    Removed from this repo: v1/ (ergogen config, footprint wrappers,
    vendored libs, ZMK skeleton, KiCad half-skeletons), docs/v1-*.md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
    [designguide-schematic.kicad_pcb, designguide-schematic.kicad_sch, thenar-v1-left.kicad_pcb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]
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2026-07-08 docs(firmware): correct the drive/sense comments - and record the full saga
    The overlay comments asserted row-gpios were the driven outputs.
    The ZMK driver says the opposite (kscan_gpio_matrix.c: col2row =>
    col-gpios are .outputs, row-gpios are .inputs, verified by cpp macro
    expansion in commit e18b2c8d). This backwards comment survived
    because on the LEFT half it never mattered - the pins were right
    even though the words were wrong - and it then seeded every wrong
    turn of the right-half bring-up. Fixed in place.
    THE FULL STORY, for the archaeologists
    =======================================
    The right half of the first thenar build produced zero keystrokes.
    Over two days the following were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
    [thenar_left.overlay]
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2026-07-08 fix(print): notch the switch plate around the reset button
    Found during first assembly: the plate's MCU-notch edge sits only
    ~0.95mm from the reset button (kbd:ResetSW) and interferes in practice
    - the first printed plate had to be hand-cut to fit over the button.
    Button position comes from the scaffold netlist: centred at
    (170.571, -101.587) in outline coordinates (mcu point + 27mm), with
    body+pads spanning 8.5 x 3.5mm. The slider (E73:SPDT_C128955) was
    checked too and already sits fully inside the open MCU notch.
    Subtract a 12 x 9mm rectangle centred on the button from the
    switchplate outline, anchored with the same expression as the reset
    footprint so they cannot drift apart. Margin cho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
    [thenar-switchplate.stl]
2026-07-08 fix(print): open the switch plate scrollwheel cutout to match the encoder
    Field report from the first assembled unit: the plate also interfered
    with the EVQWGD001 roller encoder - the wheel side of the cutout had to
    be hand-cut, while there was spare room on the side facing the board's
    centre of mass.
    Verified against the scaffold's RollerEncoder_Panasonic_EVQWGD001
    footprint (at the scrollwheel point, rot 0): the part is asymmetric,
    with pads toward the board centre and the wheel overhanging the outer
    (+x) side - envelope x -8.4..+9.8, y +-7.6 across both reversible
    mounts (body silk plus the wheel slot). The old cutout was a symmetric
    17.5x14.5 rectangle centred on the point, i.e. x +-8.7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
    [thenar-switchplate.stl]
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2026-07-08 feat(print): case v2 - power slider floor slot + drain slots
    Field-driven case fixes after assembly (corrections from Daniel:
    reset button and charge LED are TOP-side, NOT case concerns; the USB
    notch already existed - so v1's TODO list was mostly wrong).
    - Power slider access: the E73:SPDT_C128955 is an SMD slide switch
    mounted component-side-down, so its actuator faces the case floor.
    Cut a through-floor slot under it (5x11mm, elongated along the
    actuator's y travel axis) so it toggles through the closed case.
    Position derived from the mcu ergogen point + [0, 17.1] (the slider
    zone's shift), so it tracks the same anchor as the USB notch and
    can't drift.
    - Drain slots: four 2x8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
    [case.scad, thenar-case.stl]
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2026-07-19 docs(power): document v1 battery-on-RAW issue + v1 rework + v2 fix
    First battery bring-up exposed that the thenar reports a flat 0% and
    does not charge over USB. Root cause is hardware, not firmware: the
    battery is wired battery+ -> slider -> the nice!nano's RAW pin, but the
    v2's charger AND its VDDH battery-voltage sense both live on B+/B-. RAW
    feeds only the regulator, so a cell there powers the board but is
    invisible to both the charger and the gauge.
    It was wired this way because the mcu_nice_nano edge-pin footprint
    exposes no B+/B- pads - RAW was the only power-input pad, and routing
    the slider into it gave the hardware cutoff the spill-protection guide
    relies on. The cost (no sense, n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
    [config.yaml]
2026-07-19 docs(power): clean rev1/rev2 cut; rev2 = soft-off slider design
    Establishes the clean separation the hardware needs (rev1 frozen at tag
    hw-rev1, main evolves into rev2 in place):
    - battery-and-power.md restructured into background / rev1 (rc1,
    as-fabbed) / rev2 (updated design) / hypothenar sections. rev1 =
    the broken battery-on-RAW wiring + the rework for boards in hand
    (basic: LiPo -> B+/B-; advanced: also rewire slider -> P0 for
    soft-off). rev2 = battery on B+/B- + slider as a ZMK soft-off / wake
    GPIO on P0, so the switch turns the board 'off' (~uA) while USB
    charging continues - the nice!nano can't hard-cut-and-charge (B+ =
    charger = MCU supply are one node), so soft-off i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
    [config.yaml]
2026-07-19 feat(pcb): rev2 power wiring - battery on B+/B-, slider as soft-off GPIO
    Evolves the thenar power design in place toward rev2 (rev1 frozen at
    tag hw-rev1). Source + docs only; the routed board is a follow-up
    reroute (see below).
    ergogen/config.yaml:
    - battery+ (JST through-hole pad) is now the isolated net BAT_BPLUS,
    a wire-out point NOT routed to RAW. The builder solders it to the
    socketed module's B+ pad (LiPo sits in the gap under the module);
    battery- stays GND (module B- = GND, already common). Restores
    battery sensing + USB charging.
    - the slider is off the power rail: it now shorts SOFT_OFF (nice!nano
    P0) to GND, i.e. a ZMK soft-off / wake switch. Slide off ->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
    [config.yaml]
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
